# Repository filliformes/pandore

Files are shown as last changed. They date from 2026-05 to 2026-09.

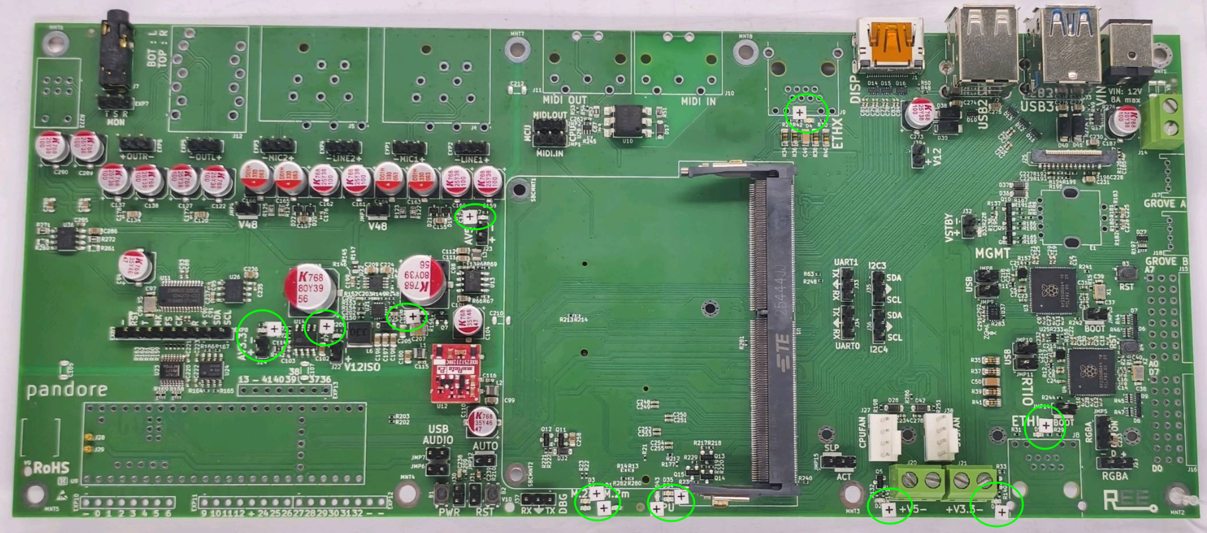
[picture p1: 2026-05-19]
doc/review/pandore-leds-review.png

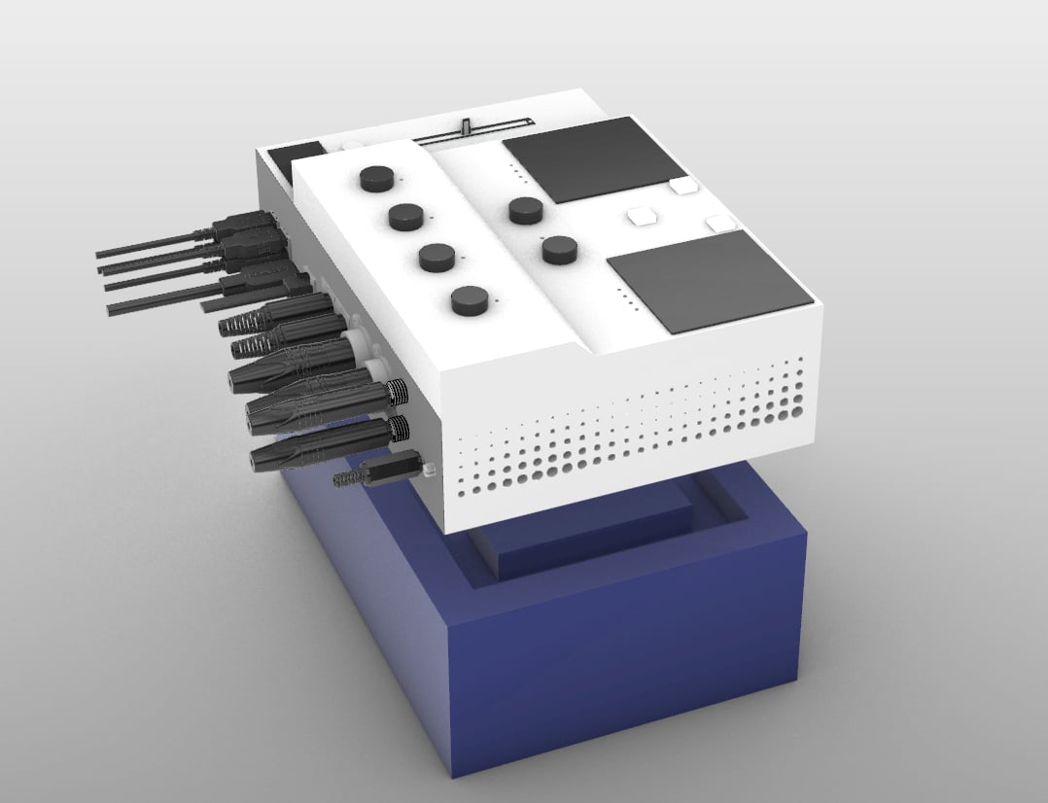
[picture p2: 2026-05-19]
doc/case+inst_v2_back.jpg

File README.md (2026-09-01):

# Pandore

Pandore A0

**Open-source digital audio instrument prototyping platform.**

Pandore is a custom-designed PCB built around the [LattePanda Mu](https://www.lattepanda.com/lattepanda-mu) compute module, a [Teensy 4.1](https://www.pjrc.com/store/teensy41.html) audio bridge, dual [RP2350](https://www.raspberrypi.com/products/rp2350/) microcontrollers, and a professional audio I/O chain. It provides a complete hardware foundation for building digital audio instruments, effects processors, and experimental sound tools.

## Status

**Revision A0** — PCBA complete at PCBWay (3 units); hand-assembly of the through-hole/DNP parts and board bring-up in progress. Manufacturing files released 2026-03-19; DRC passing. See the [interactive BOM](hw/bom/ibom.html) and the [A0 bring-up / hand-assembly guide](doc/test/bringup/pandore_a0_bringup.md).

> **PCBWay substitution:** RP2350A was unavailable at assembly time; PCBWay substituted **RP2350B (QFN-80)** for both MCU positions. RP2350A and RP2350B are binary-compatible — same cores, same peripherals, same memory map — they differ only in package size and number of exposed GPIO pins (30 vs 48). Firmware developed on RP2350A Pico boards transfers without modification.

## Board Specifications

| Parameter | Value |
|---|---|
| **Dimensions** | 260 mm x 110 mm |
| **Layers** | 4 (F.Cu / In1 / In2 / B.Cu) |
| **Components** | 804 (141 unique part numbers) |
| **Vias** | 2,217 |
| **Design tool** | KiCad 10 |

## Architecture

```
                         +-----------------+
                         |  LattePanda Mu  |
                         |  (x86-64 SBC)   |
                         +--------+--------+
                                  |
          +----------+-----------+-----------+----------+
          |          |                       |          |
 +--------+-------+  |             +---------+--------+ |
 |  RTIO MCU      |  |             |  Management MCU  | |
 |  (RP2350)      |  |             |  (RP2350)        | |
 +--------+-------+  |             +---------+--------+ |
          |          |                       |          |
 +--------+-------+  |             +---------+--------+ |
 | UART, SPI, I2C |  |             | GPIO, Power Seq, | |
 | ADC, 8x PWM    |  |             | Fan, Display     | |
 +----------------+  |             +------------------+ |
                     |                                  |
            +--------+--------+                         |
            |   Teensy 4.1    |                         |
            | (I2S-to-USB     |                         |
            |  Audio Bridge)  |                         |
            +--------+--------+                         |
                     |                                  |
            +--------+--------+               +---------+--------+
            |   CS4272 Codec  |               |   Boot, BIOS,    |
            |   (24-bit I2S)  |               |   Ethernet, M.2  |
            +-----------------+               +------------------+
```

### Compute

- **LattePanda Mu** — x86-64 SBC (Intel N100 or N305), main application processor. Recommended: DFR1147 (N100, 16 GB LPDDR5) — the N305 gives only ~13% single-core gain at ~2× cost, with no meaningful benefit for real-time audio workloads where single-thread performance dominates.
- **RTIO MCU (RP2350)** — Real-time I/O: UART, SPI, I2C, USB, ADC, 8x PWM channels
- **Management MCU (RP2350)** — System control: power sequencing, GPIO, fan, display, boot

### Audio

- **Audio/MIDI bridge:** [Teensy 4.1](https://www.pjrc.com/store/teensy41.html) — I2S-to-USB audio bridge between the CS4272 codec and the LattePanda Mu, also handles MIDI data transfer to the host computer
- **Codec:** Cirrus Logic CS4272 — stereo 24-bit ADC/DAC, I2S interface
- **Preamp:** THS4521 fully-differential amplifier + OPA1656 op-amp signal conditioning
- **Phantom power:** 48V supply via TI LM5158 flyback controller + TPS7A4001 ultra-low-noise 40V LDO post-regulation (~10 mA) for condenser microphones
- **I2S isolation:** TI ISO7762FDBQR — 6-channel digital isolator (4 forward / 2 reverse), 100 Mbps, 5000 VRMS galvanic isolation between digital and audio domains
- **I2C isolation:** TI ISO1640BDR — isolated I2C for codec control path, 2500 VRMS isolation
- **Isolated power:** Murata NXE2S1212MC-R7 — 2W isolated 12V→12V DC/DC converter (167 mA) for the isolated audio domain
- **MIDI isolation:** Isocom H11L1SMT optoisolator with Schmitt-trigger output on MIDI IN
- **Monitor output:** Dedicated headphone/speaker amplifier with hardware volume knob (Bourns PTR902-2020K-A103 — 10 kΩ audio taper, 20 mm shaft)
- **Input buffering:** Balanced input stage with line/mic switching
- **Output buffering:** Line-level outputs

### Power

| Rail | Voltage | Current | Purpose |
|---|---|---|---|
| 12V | Main input | LattePanda Mu, OLED drive |
| 5V | 2A (10W) | Digital logic, USB peripherals |
| 3.3V | 3A (10W) | MCUs, codec digital, I/O |
| 48V | 10 mA | Condenser microphone phantom power |
| AV5 / AV3P3 | — | Analog audio supply (isolated domain) |
| VSTBY | ~3.3V | Standby (CR2032 backup) |

**Power ICs:**

| Part | Role |
|---|---|
| Diodes AP63356Q (×2) | Synchronous buck converters (3.5A), main DC-DC regulation |
| STM LDL212DR (×3) | Ultra-low-dropout LDOs, local clean rails |
| ETEK ET20162 (×5) | USB VBUS current-limit load switches, 1A fixed each (U29–U32 = 4 USB-A ports, U33 = Teensy USB host) |
| TI LM5158RTER | Flyback controller for 48V phantom supply |
| TI TPS7A4001DGNR | Ultra-low-noise 40V LDO, phantom post-regulation |
| Murata NXE2S1212MC-R7 | 2W isolated 12V DC/DC (167 mA) for audio analog domain |

- Reverse-polarity, overcurrent, and overvoltage protection
- USB VBUS overcurrent handled by the ET20162 load switches (1A fixed limit each)
- PTC fuses (Bel Fuse 0ZCM0010FF2G, 0.1A) protect the **Grove ports** (J17/J18) on the standby rail
- Managed power-on sequencing via Management MCU

### Connectivity

- **Ethernet** — 2× Gigabit Ethernet via Realtek RTL8111H-CG PCIe controllers (U7, U8), 2× shielded RJ45 with isolation transformers (Würth 749020111A)
- **USB** — 4× USB-A ports (2× USB 3.0 via J3 + 2× USB 2.0 via J2) broken out from the LattePanda Mu's 8 USB lanes (remaining lanes are internal — Teensy audio bridge, AX210 WiFi/BT); plus the Teensy 4.1's own USB-C jack exposed at the back panel
- **MIDI** — 5-pin DIN IN/OUT with H11L1 optoisolation
- **Display** — 24-pin 0.5mm FPC ZIF connector (GCT FFC2A32-24-T) for OLED status display (SSD1309, 128×64 px, 1.54") — see [Components Requiring Separate Assembly](#components-requiring-separate-assembly)
- **M.2 Key-M** — PCIe x4 (NVMe SSD)
- **M.2 Key-A+E** — WiFi/Bluetooth (tested: Intel AX210 — WiFi 6E tri-band + BT 5.3) or alternate storage
- **Expansion headers** — GPIO, analog, I/O breakouts; 2× **Grove I2C connectors (3.3V, use Qwiic / STEMMA QT sensors — see below)**; I2S header; UART debug

### User Interface

- **Encoder:** Bourns PEL12T-4225T-S1024 — 24 PPR optical rotary encoder with momentary push switch and RGB LED illumination
- **Tactile switches:** 4× C&K PTS810 momentary switches (B1–B4)
- **Volume knob:** Bourns PTR902-2020K-A103 potentiometer — 10 kΩ audio taper, 20 mm shaft (monitor output level; replaces BOM part 2015K-B103, linear, 15 mm)
- **RGBA LED:** AMS-OSRAM multi-colour LEDs — blue (×3), green (×4), orange (×7), red (×1) status/indicator outputs

### Sensors

- **BMI270** — 6-axis IMU (accelerometer + gyroscope) for motion-based control

#### External sensor expansion (Grove ports)

The two Grove connectors (J17/J18) are **I2C sensor ports running at 3.3V** — each on its own management-MCU I2C bus (J17 = I2C0, J18 = I2C1), powered from the standby rail through a 0.1A PTC fuse.

Because the ports are 3.3V, use the **Qwiic / STEMMA QT** sensor ecosystem (SparkFun, Adafruit, Arduino Modulino) — it is 3.3V-native, so modules plug in safely with no level shifting. A standard **Grove-to-Qwiic adapter cable** (Adafruit #4528 or SparkFun PRT-15109) connects them. *Note: M5Stack Units are powered at 5V and are not directly compatible.*

### Flash Storage

3× Winbond W25Q128JVSIM (128 Mbit / 16 MB, QSPI):
- U2 — BIOS flash (LattePanda Mu)
- U5 — RTIO MCU flash (RP2350, U3)
- U6 — Management MCU flash (RP2350, U4)

### Thermal

- 2× 4-pin PWM fan headers (J27 CPU, J38 system), Molex KK 254 47053-1000
- **Fan header pinout: 1=GND, 2=5V, 3=Tach, 4=PWM** (fed directly from the 5V rail — note: 5V, not the 12V of a standard PC fan header)
- PWM-controlled fan driver circuit
- Three heatsink options: active cooler (DFRobot FIT0981, 5V fan), thin passive, fanless

## Audio Performance

See **[Audio Performance](AUDIO_PERFORMANCE.md)** for the full signal chain, component specs, system-level estimates, physical I/O, and performance class.

**Highlights:** 24-bit / 192 kHz, 114 dB dynamic range, -100 dB THD+N, 5000 VRMS galvanic isolation, 2× Neutrik combo XLR+TRS inputs with 48V phantom power.

## Repository Structure

```
pandore/
  hw/               Schematics (.kicad_sch) and PCB layout (.kicad_pcb)
  doc/
    arch/           Architecture diagrams (draw.io)
    img/            Board renders
    reference/      Datasheets, app notes, design guides (PDF)
  lib/              3D models (.step), KiCad symbols and footprints
  release/          Manufacturing artifacts (Gerbers, BOM, placement, 3D)
```

### Schematic Hierarchy

The top-level schematic (`pandore.kicad_sch`) references 24 sub-sheets organized by subsystem:

**Audio** — `audio`, `audio-codec`, `audio-inputs`, `audio-inbuf`, `audio-outputs`, `audio-outbuf`, `audio-isolation`, `audio-monitor`, `audio-power`

**Compute** — `computer`, `cpumod`, `mcu`, `mgmtmcu`, `rtmcu`

**Power** — `power`, `audio-power`

**Interface** — `eth`, `usbport`, `midi`, `display`, `extraport`, `mdot2`

**System** — `bootctl`, `bios`, `fan`

## Components Requiring Separate Assembly

The PCBWay PCBA order covers all SMD components. The following through-hole and DNP parts must be sourced and hand-soldered separately. BOM part numbers are listed; substitutions are noted where a different part is recommended over the original BOM.

| BOM# | Per board | Ref | Description | Part (installed) | Notes |
|---|---|-----|---|---|---|
| 40 | 1 | E1 | Encoder + RGB LED + switch | Bourns **PEL12T-4225T-S1024** | 24 PPR, push switch, RGB illuminated |
| 47 | 2 | J4, J5 | Mic/Line input combo jack | Neutrik **NCJ9FI-H-0** | XLR + 6.35mm TRS + 3-way switch |
| 50 | 2 | J8, J9 | Ethernet RJ45 | Amphenol **RJE58-188-5441** | 8P8C shielded, dual LEDs, Cat5e (replaces BOM -5411, backordered; same footprint) |
| 51 | 2 | J10, J11 | MIDI DIN | Same Sky **SDS-50J** | 5-pin DIN 180° |
| 52 | 1 | J12 | Line output TRS | Neutrik **NSJ12HF-1** | 6.35mm stacking stereo |
| 55 | 2 | J15, J16 | GPIO expansion header | Samtec **MTSW-108-22-L-T-330-RA** | 3×8 right-angle, 2.54mm pitch |
| 56 | 2 | J17, J18 | Grove connectors | TE **440055-4** | HPI 2.0mm R/A THT (replaces BOM 2041145-4, same family) |
| 105 | 1 | R273 | Headphone volume pot | Bourns **PTR902-2020K-A103** | Audio taper, 20mm shaft (replaces BOM 2015K-B103, linear, 15mm) |
| — | 1 | J25 | OLED display panel | **Microtips REX012864AYAP3N00000** (primary) or Midas MCOT128064B1V-WM (alt) | SSD1309, 128×64, 24-pin 0.5mm FPC; J25 ZIF socket is PCBWay-assembled |
| — | 1 | U9 | Audio/MIDI bridge module | **PJRC Teensy 4.1** (SparkFun DEV-20359, headerless) | Mounted on Samtec TSW headers; its own USB-C jack is exposed at the panel |
| — | 2 | J28, J29 | Teensy USB-D± pogo pins | Same Sky **CPG-23-SMT-TR** | Spring contacts tapping the Teensy's underside USB-D+/D− pads — **not** USB-C receptacles; hand-soldered |
| — | 1 | J13 | NVMe SSD | User choice | M.2 2280 Key-M, PCIe x4 |
| — | 1 | J19 | WiFi/BT module | **Intel AX210** (WiFi 6E + BT 5.3) | M.2 2230 Key-E |

---

## Manufacturing

The `release/` directory contains two packages dated 2026-03-19 (revision A0):

- **`pandore_*_A0_pcba.zip`** — PCBA package: Gerbers, drill files, BOM (.csv), pick-and-place (.pos)
- **`pandore_*_A0_release.zip`** — Full release: PCBA files + 3D assembly model (.step), assembly drawings (PDF), rendered board images, ERC/DRC reports

4-layer stackup. 2,439 drill holes. All components have manufacturer part numbers assigned.

## Reference Documentation

The `doc/reference/` directory includes datasheets and design guides used during development:

- RP2350 datasheet and hardware design guide
- LattePanda Mu evaluation kit guide and carrier board reference
- CS4272 codec (via SuperAudioBoard design guide and schematic)
- THAT1512 microphone preamp gain configuration (reference design)
- 48V phantom power supply design (TI SBOA320A + ultra-low-noise RAQ approach)
- Analog circuit design references (Analog Secrets series, AES mic preamp paper)
- THAT Corporation mic preamp reference design (git submodule)

## Requirements

- [KiCad 10](https://www.kicad.org/) to open and edit schematics and PCB layout
- [draw.io](https://app.diagrams.net/) to view architecture diagrams

## Credits

Designed by **Vincent Fillion** at [Artificiel](https://artificiel.org), with the help of **Alexandre Burton**.

Hardware engineering and KiCad source files by **Laurence Deschênes Villeneuve** ([@laurencedv](https://github.com/laurencedv)).

## License

This project is licensed under the [CERN Open Hardware Licence Version 2 — Strongly Reciprocal (CERN-OHL-S-2.0)](https://ohwr.org/cern_ohl_s_v2.txt).

You are free to use, study, modify, and distribute this design, provided that:
- You credit the original authors
- You distribute any modified versions under the same licence
- You make the source files available

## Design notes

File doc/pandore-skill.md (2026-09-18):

<!-- This document is the Pandore hardware technical reference, generated from the project's
     Claude Code skill. Personal paths, order numbers, and cost data have been removed. -->

# Pandore — Open-Source Digital Audio Instrument Prototyping Platform

Expert knowledge for developing firmware, drivers, and software for the Pandore hardware platform. Covers the complete system architecture, pin assignments, bus routing, audio signal chain, power rails, and peripheral interfaces.

**When to use:** Any work on Pandore firmware, drivers, DSP software, hardware bringup, peripheral integration, or system-level debugging.

---

## Project Location

- **Repo:** `<your local clone>/`
- **GitHub:** `filliformes/pandore`
- **Design tool:** KiCad 10
- **Status:** Revision A0 — PCBs **PCBA complete at PCBWay** (3 units), **hand-assembly + bringup in progress** (as of 2026-05-29). PCBWay received last components 2026-05-15. **iBOM and bringup doc published** by Laurence on 2026-05-19 (commit `4497a3b`): [hw/bom/ibom.html](hw/bom/ibom.html) (interactive BOM, open in browser) and [doc/test/bringup/pandore_a0_bringup.md](doc/test/bringup/pandore_a0_bringup.md) (manual-assembly checklist). Manufacturing files released 2026-03-19. The hand-assembly parts order (placed 2026-05-19) also covered the LattePanda Mu modules, Teensy boards, and active coolers, not just DNP connectors.
- **PCBWay substitution:** RP2350A unavailable; PCBWay substituted **RP2350B (QFN-80)** for both MCU positions (U3, U4). Binary-compatible — same cores, peripherals, memory map. Firmware developed on RP2350A Pico boards transfers without modification. Verify footprint accepts QFN-80 with Laurence.
- **Design by:** Vincent Fillion at [Artificiel](https://artificiel.org), with Alexandre Burton
- **Hardware engineering:** Laurence Deschênes Villeneuve ([@laurencedv](https://github.com/laurencedv))
- **Licence:** CERN-OHL-S-2.0 (strongly reciprocal — attribution + share-alike + source availability)

### Currently Available Hardware (pre-assembly dev kit)

| Item | Part | Notes |
|---|---|---|
| Host CPU | LattePanda Mu + Lite Carrier | On hand |
| Management/RTIO dev MCU | Waveshare RP2350-Plus (WAVE-29371) | 40-pin Pico 2 form factor, soldered headers, USB-C, 4MB flash |
| Networking dev | Waveshare RP2350-ETH Mini (WAVE-29266) | RP2350 + CH9121 UART-to-Ethernet chip, compact castellated form |
| OLED display | Waveshare 1.54" OLED (WAVE-25512) | SSD1309, 128×64, 7-pin SPI breakout, **onboard boost converter** |

All Management MCU firmware (display, power sequencing, IMU, fan control) is prototyped on the **RP2350-Plus** before the Pandore PCB is assembled.

> **Important difference from final board:** The Waveshare OLED module (WAVE-25512) has an **onboard boost converter** — its VCC pin accepts 3.3–5V (self-contained). The bare Midas MCOT128064B1V-WM panel on the Pandore PCB needs an **external 12V** supply on pin 23. Do not confuse the two when porting firmware.

---

## Dev Kit — Firmware Prototyping

### RP2350-Plus (WAVE-29371) — Key Facts

- **Chip:** RP2350**A** (30 GPIO) — not the RP2350B (48 GPIO) used on Pandore's RTIO MCU
- **Form factor:** 40-pin Pico 2 compatible, soldered headers
- **Flash:** 4 MB (W25Q32JV QSPI)
- **Power:** VSYS 1.8–5.5V in; 3.3V output (500 mA); USB-C
- **GPIO logic:** 3.3V only — never apply 5V to GPIO pins

**Default SPI pin assignments (Pico SDK):**

| Bus | SCK | TX (MOSI) | RX (MISO) | CSn |
|-----|-----|---|---|-----|
| SPI0 | GP18 | GP19 | GP16 | GP17 |
| SPI1 | GP10 | GP11 | GP12 | GP13 |

**Other interfaces:**

| Interface | Pins |
|---|---|
| I2C0 | GP4 (SDA), GP5 (SCL) |
| I2C1 | GP2 (SDA), GP3 (SCL) |
| UART0 | GP0 (TX), GP1 (RX) |
| UART1 | GP4 (TX), GP5 (RX) |
| ADC | GP26–GP28 (ADC0–ADC2) |

### Waveshare 1.54" OLED (WAVE-25512) — Module Pinout

7-pin header on the breakout board:

| Pin | Label | Description |
|-----|---|---|
| 1 | VCC | 3.3–5V power in (onboard boost handles OLED drive voltage) |
| 2 | GND | Ground |
| 3 | DIN | SPI MOSI (SDIN) |
| 4 | CLK | SPI SCLK |
| 5 | CS | Chip select (active low) |
| 6 | DC | Data/Command select |
| 7 | RST | Reset (active low) |

Factory default: **4-wire SPI**. I2C mode requires moving 0Ω resistors on the back of the module (not recommended — keep SPI).

### Wiring: WAVE-25512 OLED → RP2350-Plus

| OLED pin | RP2350-Plus pin | GPIO | Notes |
|---|---|---|---|
| VCC | 3V3 (pin 36) | — | Module has internal boost; 3.3V is sufficient |
| GND | GND (pin 38) | — | |
| DIN | GP19 (pin 25) | GP19 | SPI0 TX |
| CLK | GP18 (pin 24) | GP18 | SPI0 SCK |
| CS | GP17 (pin 22) | GP17 | SPI0 CSn — or manual GPIO |
| DC | GP20 (pin 26) | GP20 | Manual GPIO |
| RST | GP21 (pin 27) | GP21 | Manual GPIO |

### Software Approach for OLED

**Option A — u8g2 library (recommended for dev)**
- Constructor: `U8G2_SSD1309_128X64_NONAME0_F_4W_HW_SPI`
- Works with Pico SDK via [u8g2 Arduino port](https://github.com/olikraus/u8g2) or the [Pico-specific u8g2 port](https://github.com/Harbys/pico-ssd1306) (for SSD1306 but same pattern)
- Handles init sequence, SSD1309 command set, display buffer

**Option B — Raw Pico SDK SPI**
```c
// Init SPI0 at 10 MHz
spi_init(spi0, 10 * 1000 * 1000);
gpio_set_function(18, GPIO_FUNC_SPI); // SCK
gpio_set_function(19, GPIO_FUNC_SPI); // MOSI
gpio_init(17); gpio_set_dir(17, GPIO_OUT); // CS
gpio_init(20); gpio_set_dir(20, GPIO_OUT); // DC
gpio_init(21); gpio_set_dir(21, GPIO_OUT); // RST
```
- SSD1309 init sequence: send `0xAE` (Display Off) → config commands → clear GRAM → `0xAF` (Display On)
- Write: pull CS low, set DC high (data) or low (command), `spi_write_blocking(spi0, buf, len)`, pull CS high

**Power-up sequence (same for module and bare panel):**
1. VCC on → RST low (1 ms) → RST high → send `0xAE` → init registers → clear screen → delay 100 ms → send `0xAF`

### Build Environment (Pico SDK on Windows)

> ⚠️ **The Docker path and the official Windows installer both fail for RP2350 on this Windows dev machine** — see [Software & Firmware Development](#software--firmware-development) for the *verified working* toolchain recipe (SDK 2.1.1 cloned manually + v1.5.1 toolchain binaries + prebuilt picotool 2.1.1). What does NOT work, and why:
> - **Docker Desktop:** its WSL2 backend is disabled here (`Wsl/0x80070422`) — the daemon returns HTTP 500 on every call.
> - **`pico-setup-windows` installer:** ships **SDK 1.5.1 only**, which is RP2040-era and **cannot build RP2350** (no `rp2350-arm-s` platform). Useful only for its bundled arm-gcc / ninja / cmake binaries.

**CMakeLists.txt minimum for SPI + OLED:**
```cmake
cmake_minimum_required(VERSION 3.13)
include($ENV{PICO_SDK_PATH}/external/pico_sdk_import.cmake)
project(pandore_oled C CXX ASM)
pico_sdk_init()

add_executable(pandore_oled main.c)
target_link_libraries(pandore_oled pico_stdlib hardware_spi hardware_gpio)
pico_add_extra_outputs(pandore_oled)  # generates .uf2
```

**Flash:** hold BOOTSEL on RP2350-Plus while plugging USB → appears as mass storage → drag `.uf2` file onto it.

### RP2350-ETH Mini (WAVE-29266) — Notes

- **Ethernet chip:** CH9121 (UART-to-Ethernet bridge, not native Ethernet MAC)
- **Interface:** RP2350 talks to CH9121 over UART at configurable baud rate
- **Only 14 GPIO exposed** (castellated half-holes) — compact for integration
- CH9121 config registers set: IP, gateway, subnet, port, mode (TCP/UDP server/client) via UART commands
- Example code: `CH9120.c` / `CH9120.cpp` config files from Waveshare
- **Use case on Pandore:** prototype network-based control / OSC / remote config before Pandore PCB arrives

---

## Software & Firmware Development

How Pandore software is actually built, where it lives, and the verified toolchain — as opposed to the aspirational advice elsewhere. Written from real bring-up (2026-05).

### Host OS — Linux (CachyOS)

The LattePanda Mu host runs **Linux, specifically CachyOS** (Arch-based,
performance-tuned). Confirmed 2026-09-18. The eMMC Mu ships with Win11
preinstalled; it is wiped. This matches the production plan (one C++20 daemon,
audio via JACK/PipeWire).

**The Windows Pico-SDK toolchain saga documented below is a *dev-PC* artifact,
not the Mu target.** On Arch the RP2350 build is trivial: `arm-none-eabi-gcc` +
newlib + cmake + ninja, with `picotool` from the AUR.

Arch/CachyOS gotchas that differ from Debian/Ubuntu:

- **Serial group is `uucp`, not `dialout`** — for `/dev/ttyACM*` (RP2350 CDC and
  Teensy).
- **Python is PEP-668 externally-managed** — use `pipx`/venv or the
  `python-pyserial` pacman package for `host_bridge`; bare `pip install` fails.
- **Realtime audio:** add the user to `audio` + `realtime`, set
  `@audio - rtprio 95` and `memlock unlimited`. CachyOS's default BORE kernel is
  already low-latency.
- **udev rules** needed for flashing: `99-picotool.rules` and PJRC's
  `00-teensy.rules`.

### Firmware repo

The firmware does **not** live in this `pandore` hardware repo (that's KiCad + CERN-OHL-S). It lives in a **separate firmware repo**, MIT-licensed, laid out as:

```
<firmware-repo>/
  recherche/oled-usb-menu/        research sandbox — OLED menu prototype
    mgmtmcu_menu/                  RP2350 firmware (Pico SDK C)
      src/                         main.c, oled_ssd1309, gfx, font5x7,
                                   menu, menu_items, input, host_link, board_pins.h
      CMakeLists.txt  build.ps1  Dockerfile(dead)  README.md
    host_bridge/                   LattePanda-side Python (pyserial → Max/Pd/SC)
```

> **Status:** the menu firmware is a **throwaway prototype**. The production plan is a single C++20 daemon that owns all hardware and speaks **binary USB framing** to the two RP2350s ("Slot 0" / "Slot 1"). The prototype's text protocol is for fast iteration; it will be re-homed onto the daemon's binary framing once the concept is proven. Do not expect it to plug into `firmware/slot0` as-is.

### Verified Windows toolchain (RP2350)

The **only** combination proven to build RP2350 firmware here. Docker and the official installer both fail (see the Build Environment warning above).

| Piece | Location | How it got there |
|---|---|---|
| Pico SDK **2.1.1** | `%USERPROFILE%\pico-sdk\sdk-2.1.1` | `git clone --branch 2.1.1` + `git submodule update --init` (pulls TinyUSB etc.) |
| arm-none-eabi-gcc 10.3, cmake, ninja, python | `C:\Program Files\Raspberry Pi\Pico SDK v1.5.1\` | reused from the `pico-setup-windows` v1.5.1 install (its binaries are fine; only its SDK is too old) |
| **picotool 2.1.1** (prebuilt) | `%USERPROFILE%\pico-sdk\picotool-2.1.1\picotool` | downloaded `picotool-2.1.1-x64-win.zip` from `pico-sdk-tools` releases — the from-source build fails (no host x86 compiler) |

Key CMake settings: `PICO_BOARD=pico2`, `PICO_PLATFORM=rp2350-arm-s`. Pass `-Dpicotool_DIR=<...>\picotool` so CMake doesn't try to build picotool from source. `build.ps1` wires all of this up and takes `-Target DEVKIT|PANDORE`.

```powershell
cd <firmware-repo>\recherche\oled-usb-menu\mgmtmcu_menu
.\build.ps1                    # DEVKIT  → build-devkit\mgmtmcu_menu.uf2
.\build.ps1 -Target PANDORE    # Pandore → build-pandore\mgmtmcu_menu.uf2
```

### Dual-target pin map (`board_pins.h`)

One source tree builds for both boards via a compile-time switch (`PANDORE_TARGET` → `PANDORE_BOARD_DEVKIT` / `PANDORE_BOARD_PANDORE`). Dev-kit pins are in [Wiring: WAVE-25512 OLED → RP2350-Plus](#wiring-wave-25512-oled--rp2350-plus). The **Pandore Management MCU** map, traced from `pandore-mgmtmcu.kicad_sch` through the reusable `pandore-mcu` sub-sheet:

| Function | RP2350B GPIO | Net | Note |
|---|---|---|---|
| OLED CS | 33 | SDISP.~{SS} | SPI0 CSn |
| OLED SCK | 34 | SDISP.SCK | SPI0 SCK |
| OLED MOSI | 35 | SDISP.MOSI | SPI0 TX |
| OLED RST | 36 | SDISP.~{RST} | GPIO |
| OLED DC | 37 | SDISP.~{LATCH} | GPIO (D/C#) |
| Encoder A | 31 | ENC.A | |
| Encoder B | 30 | ENC.B | |
| Encoder BTN | 32 | ENC.BTN | |
| Enc LED R / G / B | 43 / 46 / 47 | ENC.RED/GREEN/BLUE | PWM-capable |

GPIO33/34/35 are the RP2350B's **native SPI0 alt-function pins** (datasheet Table 645), so the OLED runs on hardware SPI with no PIO. Pandore has no discrete nav buttons — the encoder owns navigation, so `BTN_PIN_*` are `-1` and `input.c` skips them.

### USB-CDC wire protocol (prototype)

Text, line-based, `\n`-terminated. Trivial to debug in a serial monitor.

```
MCU  → host:  LOAD <max|pd|sc> <path>   |  STOP  |  ENC <delta>
host → MCU:   STATUS cpu=<int> name=<text>  |  OK  |  ERR <msg>  |  INPUT <u|d|s|b>
```

`host_bridge/bridge.py` (pyserial) launches Max/Pd/SC on `LOAD`, kills on `STOP`, pushes `STATUS` ~1 Hz, and lets you drive the menu from stdin (`u/d/s/b`) when no encoder is wired. A binary **`FRAME` opcode (1024-byte 128×64 mono buffer) is reserved** for the eventual Schwung-renderer port — the day the menu is rendered host-side and pushed to a dumb display MCU.

### Expansion-header firmware map

GPIO/PWM assignments needed to write code against the expansion headers (traced from schematic — see [Expansion](#expansion) for the hardware side). **All 16 AIO/DIO signals carry a 560 Ω series resistor + TVS clamp**, so they are protected but *not* low-impedance drivers.

- **J15 AIO** (RTIO MCU): GPIO40–47 = ADC0–7, also PWM 8A–11B. Column B = VRTIO (= V3P3, unswitched, unfused). Column C = GND.
- **J16 DIO** (RTIO MCU): GPIO12,13,14,15,20,21,22,23 = PWM 6A,6B,7A,7B,2A,2B,3A,3B.
- **J17/J18 Grove** (Mgmt MCU): I2C0 = GPIO41(SCL)/40(SDA), I2C1 = GPIO39(SCL)/38(SDA). V+ is **PTC-fused** (~100 mA).
- **J33–J36** (LattePanda Mu native): UART0/1 and I2C3/4 straight off the x86 host — bypass both MCUs. GND is the centre pin (anti-reverse); no power pin.
- **J26 "RGBA"** (Mgmt MCU): dedicated **WS2812/SK6812 addressable-LED port** — GPIO on the Mgmt MCU → 74LVC1G17 buffer (5 V level shift) → data. `JMP5` selects V5 onto the port. This — not the AIO/DIO headers — is the intended way to drive an RGB LED. Direct RGB drive off AIO/DIO is starved (3.3 V through 560 Ω ≈ 2 mA red, <0.5 mA green/blue).

### Firmware targets (recap)

1. **Teensy 4.1** — Arduino/PlatformIO, Teensy Audio Library: I2S ↔ USB Audio, USB MIDI, CS4272 I²C control.
2. **RP2350B RTIO MCU** — Pico SDK: real-time I/O, ADC, 8× PWM, sensors.
3. **RP2350 Management MCU** — Pico SDK: OLED menu, encoder, RGB, power sequencing, IMU. (**Not** fans — see Thermal.) ← the `mgmtmcu_menu` prototype targets this.
4. **LattePanda Mu** — x86-64 Linux/Windows: main app host, DSP (JACK/PipeWire/ASIO), and the production daemon.

---

## System Architecture

```
                    ┌─────────────────────┐
                    │   LattePanda Mu     │
                    │   (x86-64 SBC)      │
                    │                     │
                    │  UART0-2, I2C2-5    │
                    │  8× USB (3×USB3,    │
                    │         5×USB2)     │
                    │  4× PCIe lanes      │
                    │  HDMI (DDIB)        │
                    │  BIOS (QSPI)        │
                    │  GPP_A/B/D/E/F GPIO │
                    └──┬───┬───┬───┬──┬──┘
                       │   │   │   │  │
          ┌────────────┘   │   │   │  └────────────┐
          │                │   │   │               │
    ┌─────┴──────┐   ┌────┴───┴┐  │    ┌──────────┴──────┐
    │ Teensy 4.1 │   │ RP2350B │  │    │ Management MCU  │
    │ Audio/MIDI │   │ RTIO MCU│  │    │ (RP2350)        │
    │ Bridge     │   │         │  │    │                 │
    │            │   │ 48 GPIO │  │    │ BMI270 IMU      │
    │ I2S ↔ USB  │   │ UART×2  │  │    │ (fans: see CPU) │
    │ MIDI ↔ USB │   │ SPI×2   │  │    │ Power Seq       │
    │            │   │ I2C     │  │    │ Boot/Reset      │
    │ CS4272     │   │ USB     │  │    │ Display Ctl     │
    │ codec ctl  │   │ ADC     │  │    │ RGBA LED        │
    └────────────┘   │ 8× PWM  │  │    └─────────────────┘
                     │ QSPI    │  │
                     └─────────┘  │
                                  │
                    ┌─────────────┘
                    │
            ┌───────┴───────┐
            │  Peripherals  │
            │               │
            │ Ethernet(PCIe)│
            │ M.2 Key-M     │
            │ M.2 Key-A+E   │
            │ HDMI display  │
            │ Expansion hdr │
            └───────────────┘
```

---

## Audio Subsystem

### Signal Chain

```
Mic/Line Input → THS4521 Diff Amp + OPA1656 → Input Buffer → CS4272 ADC
                                                       │
                                                   I2S bus
                                                       │
                                              ┌────────┴────────┐
                                              │   Teensy 4.1    │
                                              │  (I2S ↔ USB     │
                                              │   Audio Bridge) │
                                              └────────┬────────┘
                                                       │
                                                  USB Audio
                                                       │
                                                LattePanda Mu
                                                       │
                                                  USB Audio
                                                       │
                                              ┌────────┴────────┐
                                              │   Teensy 4.1    │
                                              └────────┬────────┘
                                                       │
                                                   I2S bus
                                                       │
                                              CS4272 DAC → Output Buffer → Line Out
                                                                        → Monitor Amp (volume knob) → Headphones
```

### CS4272 Codec (U11)

- **Part:** CS4272K-CZZR (Cirrus Logic)
- **Format:** I2S, 24-bit, up to 192 kHz
- **Datasheet:** https://statics.cirrus.com/pubs/proDatasheet/CS4272_F2.pdf

**I2S Signals:**
| Signal | Description |
|---|---|
| `DATA.TXD0` | I2S transmit data (ADC → MCU) |
| `DATA.RXD0` | I2S receive data (MCU → DAC) |
| `DATA.TXFS` | I2S frame sync (LRCLK) |
| `DATA.TXCLK` | I2S bit clock (BCLK) |
| `DATA.MCLK` | Master clock |

**Control (I2C):**
| Signal | Description |
|---|---|
| `CTL.SDA` | I2C data |
| `CTL.SCL` | I2C clock |

**Audio Signals:**
| Signal | Description |
|---|---|
| `LEFT.SIG+`, `LEFT.SIG-` | Balanced line output L |
| `RIGHT.SIG+`, `RIGHT.SIG-` | Balanced line output R |
| `MICLINE1.SIG+`, `MICLINE1.SIG-` | Mic/line input 1 |
| `MICLINE2.SIG+`, `MICLINE2.SIG-` | Mic/line input 2 |
| `~{MUTE}.L`, `~{MUTE}.R` | Mute control (active low) |
| `VCM0`, `VCM1`, `VCM2` | Virtual ground references |

**Hierarchical I2S Bus Labels (inter-sheet routing):**
| Label | Description |
|---|---|
| `CODEC{I2S1DPX}` | Codec-side I2S bus |
| `CPU{I2S1DPX ~{RST}}` | LattePanda Mu I2S bus |
| `MCU{I2S1DPX ~{RST}}` | RP2350 MCU I2S bus |
| `DATA{I2S1DPX}` | Data-side I2S bus |
| `AUDMST{I2C}` | Audio master I2C bus |
| `CODEC{I2C}` | Codec I2C bus |

**Audio Domain Isolation:**

| Part | Designator | Type | Role |
|---|---|---|---|
| TI ISO7762FDBQR | U23 | 6-ch digital isolator, 100 Mbps, 5000 VRMS | I2S bus isolation (4 fwd / 2 rev) |
| TI ISO1640BDR | U24 | Isolated I2C, 1 Mbps, 2500 VRMS | Codec I2C control isolation |
| Murata NXE2S1212MC-R7 | U12 | **2W** isolated DC/DC, 12V→12V (167 mA, ±1500 VDC isolation) | Isolated power for VSSISO domain — **PCBWay-assembled**, see schematic `pandore-audio-power` |
| Isocom H11L1SMT | U10 | Optoisolator with Schmitt trigger | MIDI IN isolation |

- Separate analog ground (AVSS, VSSISO) from digital ground (VSS)
- ±8 kV IEC 61000-4-2 contact discharge ESD protection on ISO7762

### Microphone Preamp

- **Differential amplifier:** TI THS4521IDGKR (U15, U16, U17, U18) — fully-differential, low-noise, wideband
- **Signal conditioning:** TI OPA1656IDR (U26, U34, U35, U36) — dual low-noise op-amp (SOIC8)
- **Reference docs:** THAT1512 DN138 and thatmicpre submodule (reference designs, not used in final BOM)

### 48V Phantom Power

- Ultra-low-noise step-up converter
- ~10 mA output (sufficient for condenser microphones)
- Passive output filtering
- Design references: TI SBOA320A, RAQ ultra-low-noise approach

### Monitor Output

- Dedicated headphone/speaker amplifier
- **Volume knob:** Bourns PTR902 dual-gang potentiometer with rotary switch (R273, DNP)
  - **BOM part:** PTR902-2015K-B103 (10 kΩ, linear taper, 15 mm shaft)
  - **Installed part:** PTR902-2020K-A103 (10 kΩ, **audio taper**, **20 mm shaft**) — longer shaft for panel clearance; audio taper gives more natural volume feel (Mouser: 652-PTR902-2020KA103)
  - Footprint: `reekilib_pot:bourns_PTR902` (same for both shaft lengths)
- Independent from line outputs

#### Verified from Rev A0 netlist — R273 wiring, isolation, and the rotary switch

R273 is an 8-pad part: two audio gangs plus a rotary switch. Pad → net, from
`pandore.kicad_pcb`:

| Pad | Net | Function |
|---|---|---|
| 1 | `Net-(U34A-OUT)` | L signal in, from OPA1656 `U34A` |
| 2 | `Net-(R264-Pad1)` | **L wiper** → `R264` (5.1 kΩ) |
| 3 | `Net-(U36A-IN-)` | `U36A` inverting input |
| 4 | `Net-(U35A-OUT)` | R signal in, from `U35A` |
| 5 | `Net-(R269-Pad1)` | **R wiper** → `R269` (5.1 kΩ) |
| 6 | `Net-(U36B-IN-)` | `U36B` inverting input |
| 7 | `AV5` | rotary switch pole |
| 8 | `Net-(U34A-V+)` | rotary switch pole → monitor op-amp V+ rail |

Both wipers feed 5.1 kΩ resistors into an OPA1656 summing junction — a
Baxandall-style **active** volume control, not a plain divider to ground.
This is why the monitor path keeps its noise performance at low settings.

**The pot cannot be read by any processor, and must not be wired to one.**
Neither wiper reaches an ADC anywhere on the board. The whole monitor chain
(`U34`/`U35`/`U36`, the pot) runs on `AV5` referenced to **`AVSS`** — the
isolated analog domain. Exactly 12 components bridge `VSS` (digital) and
`AVSS`, and every one is either an isolator or a barrier capacitor:

- `U23` ISO7762 (I²S), `U24` ISO1640 (I²C), `U12` NXE2S1212 (isolated DC/DC)
- `C105`–`C109`, `C210`–`C213` — AC coupling across the barrier

There is **no 0 Ω link, ferrite, or star point** joining the two grounds; they
are separate at DC. Running a wire from a wiper to a Teensy or MCU ADC would
short the barrier, destroying the 5000 V<sub>RMS</sub> isolation and injecting
digital ground noise into the analog ground — which is precisely what the
isolation exists to prevent, and what the 114 dB dynamic-range figure depends
on.

**If you want software-readable volume, use one of these instead:**

1. **Encoder + codec digital volume (recommended).** The Mgmt MCU already owns
   the encoder and can write the CS4272 DAC volume registers (`0x04`/`0x05`)
   over the existing isolated I²C. Affects both outputs, no new hardware, no
   isolation compromise. The analog pot stays as the final headphone trim
   after the DAC, which is the correct place for it.
2. **I²C ADC on the isolated side.** `EXP8` is a populated 2-pin header on
   `CTL.SDA`/`CTL.SCL` — the codec side of `U24`, already in the AVSS domain.
   An ADS1115 there (powered from `AV3P3`/`AV5`, buffered off the wiper) is
   readable through the isolator that is already in place. Note that bus
   carries **ERR-001**, so any add-on must follow the same swapped convention
   as the codec (its SCL to `EXP8.2`, its SDA to `EXP8.1`).
3. **Digital pot or VCA** in the signal path, commanded over the isolated I²C.
   Rev B territory.

**Rotary switch — live, and a bring-up gotcha.** Pads 7/8 sit in parallel with
`R275`, which links `AV5` to the monitor op-amps' V+ rail. `R275` is **0 Ω and
marked DNP**, so on Rev A0 boards the switch is *not* bypassed: the monitor
op-amps are powered only when the switch is closed. **If the headphone output
is dead, check the knob is not at the off detent before suspecting the
amplifier.** Fitting a 0 Ω at `R275` defeats the switch and makes the monitor
stage always-on. The switch is not connected to any MCU either, so it cannot
be read in software.

### Audio Power Rails

| Rail | Description |
|---|---|
| `AV3P3` | 3.3V analog supply |
| `AV5` | 5V analog supply |
| `AVSS` | Analog ground |
| `VSSISO` | Isolated analog ground |

### Physical Audio I/O

| Connector | Part | Type |
|---|---|---|
| Mic/Line In (×2) | Neutrik NCJ9FI-H-0 | Combo XLR + 6.35mm TRS + 3-way switch |
| Line Out (×1) | Neutrik NSJ12HF-1 | 6.35mm TRS |
| Monitor | Same Sky SJ3-35083B-TR | 3.5mm TRS |
| MIDI In/Out | Same Sky SDS-50J (×2) | 5-pin DIN |
| Teensy USB-D± tap (J28, J29) | Same Sky CPG-23-SMT-TR (×2) | **Pogo pin** (spring contact, NOT USB-C). Contacts Teensy's bottom-side USB-D+/D- pads. Teensy's own USB-C jack is what's exposed at Pandore's panel. |

### Audio Performance

**Component-level specs:**

| Component | Role | Key Specs |
|---|---|---|
| CS4272 (Cirrus Logic) | Stereo codec | 24-bit, 4–192 kHz, 114 dB DR (A-wtd), -100 dB THD+N |
| THS4521 (TI, ×4) | Fully-diff amp | 4.6 nV/√Hz, -112 dB THD+N @ 1 kHz, 145 MHz BW, 490 V/µs, 102 dB CMRR |
| OPA1656 (TI, ×4) | Dual op-amp | 2.9 nV/√Hz, -131 dB THD @ 1 kHz, 53 MHz GBW, 24 V/µs |
| ISO7762 (TI) | I2S isolator | 6-ch, 100 Mbps, 11 ns delay, 5000 VRMS |

**System-level estimates** (CS4272 codec is the limiting factor, not the analog front-end):

| Parameter | Expected Value |
|---|---|
| Dynamic range | 112–114 dB (A-weighted) |
| THD+N (system) | -98 to -100 dB (codec-limited) |
| Noise floor | ~-114 dBFS (A-weighted) |
| Max sample rate | 192 kHz / 24-bit |
| USB audio latency | ~5–10 ms round-trip (buffer-dependent) |
| Frequency response | 20 Hz – 90 kHz (at 192 kHz) |
| Phantom power | 48V / 10 mA |
| Channel separation | >100 dB |
| Galvanic isolation | 5000 VRMS (digital ↔ audio domain) |

**Performance class:** Comparable to prosumer interfaces (Focusrite Scarlett, MOTU M4). The analog front-end is essentially transparent — the OPA1656's -131 dB THD provides substantial headroom over the codec. The 114 dB dynamic range is well above the noise floor of any instrument prototyping scenario.

---

## Teensy 4.1 — Audio/MIDI Bridge

- **Part:** PJRC Teensy 4.1 (NXP i.MX RT1062, ARM Cortex-M7 @ 600 MHz)
- **Sourcing:** SparkFun **DEV-20359** (headerless Teensy 4.1) at Mouser is the version Vincent used
- **Footprint:** `reekilib_som:teensy_4.1` — 2.54 mm pitch THT, 24+24 long-row pins + 5-pin USB host row
- **Datasheet:** https://www.pjrc.com/store/teensy41.html
- **Role:** Bridges I2S audio and MIDI data between the CS4272 codec and the LattePanda Mu over USB

### Mounting — direct-solder header stack

The Teensy is held entirely by **soldered pin headers** (no separate mechanical screws). Both boards share a single set of male pin headers; the plastic insulator acts as a fixed mechanical spacer between the two PCBs.

```
       ┌─────────────────────┐  ← Teensy 4.1 PCB top  (solder pins here)
       │ Teensy 4.1 (1.6 mm) │
       ├─────────────────────┤  ← Teensy bottom (rests on plastic)
       │   plastic 2.54 mm   │  ← INSULATOR = board-to-board gap
       ├─────────────────────┤  ← Pandore PCB top (rests on plastic)
       │ Pandore PCB (1.6 mm)│
       └─────────────────────┘  ← Pandore PCB bottom (solder pins here)
```

| Qty per board | Part | Mouser # | Notes |
|---|---|---|---|
| 2 | Samtec **TSW-124-07-T-S** | 200-TSW12407TS | 24-pin male, 2.54 mm pitch, **2.54 mm plastic** (sets the gap), mating post 5.84 mm / termination post 2.54 mm, tin |
| 1 | Samtec **TSW-105-07-T-S** | 200-TSW10507TS | 5-pin male, same family, for USB host row |

> ⚠️ **The 2.54 mm gap puts the CPG-23 pogo pins (J28/J29) at near-maximum compression.** CPG-23 working height is 2.50–2.90 mm (normal 2.70). 2.54 mm is within spec but only 0.04 mm above the max-compression limit. Reliable for static mount but tight — if a future revision adjusts the gap target, switching to a header with a 2.70 mm insulator would be ideal.

### USB-D± routing (J28, J29 pogo pins)

Pandore taps the Teensy's bottom-side USB-D+/D- exposed pads via **2× spring-loaded pogo pins** at positions J28 and J29:

| Position | Signal | Part |
|---|---|---|
| J28 | `AUDIO.D-` | Same Sky CPG-23-SMT-TR (Ø1.80 mm pad / Ø1.35 mm hole) |
| J29 | `AUDIO.D+` | Same Sky CPG-23-SMT-TR (Ø1.80 mm pad / Ø1.35 mm hole) |

When the Teensy is socketed onto its TSW header stack, the pogo pins make spring contact with the Teensy's underside pads — wiring USB-D± from the Teensy into Pandore's audio USB lane (`AUDIO.USB{USB2}` → LattePanda Mu) without any wires. The Teensy's own USB-C jack remains accessible at Pandore's back panel for direct user connection.

**Soldering order matters when stacking:**
1. Hand-solder the **CPG-23 pogo pins** to J28, J29 first (Pandore PCB, fine SMT work)
2. Insert TSW pin headers into Pandore PCB through-holes, plastic insulators flush on top
3. Set the Teensy on top, pins through its through-holes
4. Solder the **Teensy side first** (top pins) — locks the geometry
5. Flip and solder the Pandore PCB side

**Teensy Connections:**

| Teensy Pin/Bus | Connected To | Description |
|---|---|---|
| `CODEC{I2S1DPX}` | CS4272 I2S bus | I2S audio data to/from codec |
| `CPU{I2S1DPX ~{RST}}` | LattePanda Mu | I2S passthrough / USB audio |
| `MCU{I2S1DPX ~{RST}}` | RP2350 MCU | I2S interface to RTIO MCU |
| `USBH.VUSB` | USB host power | USB host bus voltage |
| `USBH.D-`, `USBH.D+` | USB host data | USB host data lines |
| `USBD.VUSB` | USB device power | USB device bus voltage |
| `USB{USB2}` | LattePanda Mu | USB 2.0 connection to host CPU |

#### USB path to the host — and the power gate that bites

The Teensy reaches the Mu on **`USB2_P6` (edge pins 112/114)** via the `J28`/`J29`
pogo pins and series jumpers **`JMP6`/`JMP7`**.

> **The confound that makes a pogo-path test meaningless if skipped.** The
> Teensy's `VIN` is **unconnected**. On the pogo path its *only* supply is
> `USBD.VUSB` (pad 59) ← **`U33`** (ET20162 load switch) ← `V5`, whose **enable is
> `AUDIO.EN` = Mu `GPP_F12`**. If the host never drives `GPP_F12` high, `U33`
> stays off, the Teensy is unpowered, and it will not enumerate **on any BIOS**.
> With a USB-C cable it is powered by that port's VBUS instead — which is why
> cabling "works" and the pogo path appears dead.
>
> Any pogo-path test must: (1) fit `JMP6`/`JMP7`, (2) drive `GPP_F12` high,
> (3) measure 5 V on Teensy pad 59. Only then does a negative result implicate
> the BIOS. **The pin-13 LED is not a power indicator.**
>
> **The production daemon must assert `GPP_F12` as part of power sequencing, or
> there is no audio interface at all.**

Also: stock Mu BIOS declares `USB2_P6` "dedicated for USB Type-C ... cannot be
used as a standard USB port". LattePanda's own design guide confirms this is
**firmware policy, not silicon**. Bench-confirmed 2026-09-13: with `JMP6`/`JMP7`
fitted and 5 V present, the Teensy does **not** enumerate over the pogo path on
stock BIOS, but **does** when cabled from its own USB-C to a Pandore USB-A port.
Device and firmware are fine; the port is the difference.

Leave the Teensy's underside `VUSB`↔`VIN` pads **intact** — the common "cut for
external power" mod kills the pogo path. No spare USB2 lane exists as a
fallback; all 8 are allocated.

**Firmware responsibilities:**
1. Class-compliant USB Audio device (I2S ↔ USB bridge)
2. MIDI data transfer (DIN → USB MIDI → LattePanda Mu) — **only when
   `JMP1`/`JMP2` are set to the Teensy (1–2)**; the DIN ports are
   jumper-shared with the Mu's UART2. Teensy side is `Serial8`
   (IO34 RX / IO35 TX). See [MIDI Interface](#midi-interface).
3. Codec I2C control (configuration, sample rate, gain)

---

## RP2350B — RTIO MCU (U3)

- **Part:** RP2350B-TR13 / RP2350B-TR7 (Raspberry Pi)
- **Core:** Dual ARM Cortex-M33 or dual RISC-V Hazard3 @ 150 MHz
- **Package:** QFN-80 (48 GPIO) — PCBWay substituted RP2350B for RP2350A; same binary interface, only differs in package footprint
- **Flash:** W25Q128JVSIM (128 Mbit = 16 MB, QSPI) — same part used for all 3 processors (U2/U5/U6)

### GPIO Map (48 lines: GPIO0–GPIO47)

All 48 GPIOs are exposed via hierarchical labels. Key alternate functions:

| Function | Pins |
|---|---|
| UART0 TX/RX | Configurable (any GPIO via PIO) |
| UART1 TX/RX | Configurable (any GPIO via PIO) |
| SPI0 (MOSI/MISO/SCK/CS) | Configurable |
| SPI1 (MOSI/MISO/SCK/CS) | Configurable |
| I2C | Configurable |
| USB D+/D- | GPIO7 / GPIO6 |
| ADC | GPIO26-GPIO29 (ADC0-ADC3) |
| PWM | 8 channels on configurable pins |

**USB Signals:**
| Signal | GPIO | Description |
|---|---|---|
| `_USB.D+` / `USB.D+` | GPIO7 | USB data positive |
| `_USB.D-` / `USB.D-` | GPIO6 | USB data negative |

**QSPI Flash Bus:**
| Signal | Description |
|---|---|
| `QSPI.SCK` | SPI clock |
| `QSPI.D0`–`QSPI.D3` | Quad SPI data |
| `QSPI.~{CS}` | Chip select (active low) |

---

## Management MCU (RP2350)

Connected to the LattePanda Mu for system-level control.

### Responsibilities

- Power-on sequencing
- Boot/reset control
- Display management
- RGBA LED output
- BMI270 IMU reading

### BMI270 IMU

- **Type:** 6-axis (accelerometer + gyroscope)
- **Interface:** I2C or SPI (connected to management MCU)
- **Use case:** Motion-based instrument control (tilt, shake, orientation)

### Fan Control — *not* owned by this MCU

> **Correction (verified 2026-09 from the netlist).** The fans are driven by the
> **LattePanda Mu**, not the Management MCU. `FANCPU{TAC PWM}` and
> `SYSCPU{TAC PWM}` terminate in `pandore-cpumod.kicad_sch` on the Mu's native
> `FAN_CTL`/`FAN_TAC` edge pins. The strings `FANCPU`/`SYSCPU` appear **zero**
> times in `pandore-mgmtmcu.kicad_sch`. Confirmed independently by Laurence.
>
> Consequence: fan speed is handled by the Mu's BIOS/OS thermal management
> (ACPI / `hwmon` on Linux). **No MCU firmware is needed, or able, to control
> them.** See [Thermal](#thermal).

### OLED Status Display

#### Selected Part

- **Part:** Midas Displays MCOT128064B1V-WM
- **Source:** DigiKey.ca (PN: MCOT128064B1V-WM, DigiKey #21322651)
- **Datasheet:** https://www.farnell.com/datasheets/2830019.pdf
- **Alternate sources:** Farnell (PN 2817922), RS Components (PN 249-2717)

#### Display Specifications

| Parameter | Value |
|---|---|
| Type | Graphic OLED, passive matrix, COG (chip-on-glass) |
| Resolution | 128 × 64 pixels |
| Diagonal | 1.54" |
| Driver IC | SSD1309ZC |
| Appearance | White on black |
| Module size | 42.04 × 27.22 × 1.45 mm |
| Active area | 35.05 × 17.51 mm |
| Pixel pitch | 0.274 × 0.274 mm |
| Contrast ratio | 2000:1 |
| Brightness | 100–120 cd/m² (50% checkerboard) |
| Viewing angle | 160° (H/V) |
| Operating temp | -40°C to +80°C |
| OLED lifetime | 20,000 hours (25°C, 50% checkerboard) |

#### Electrical Characteristics

| Parameter | Symbol | Min | Typ | Max | Unit |
|---|---|-----|-----|-----|---|
| Logic supply | VDD | 2.80 | 3.00 | 3.30 | V |
| Display supply | VCC | 12.00 | 12.50 | 13.00 | V |
| Operating current (50% checker) | IDD | — | 16 | 45 | mA |

#### FPC Connector

- **FPC:** 24-pin, 0.5 mm pitch, top contact
- **Mating connector:** GCT FFC2A32-24-T (ZIF, slide lock, SMT)
- **FPC contact width:** P0.5 × 23 = 11.5 mm

#### Pinout (24-pin FPC)

| Pin | Symbol | Function | Pandore Connection (SPI mode) |
|-----|---|---|---|
| 1 | NC (GND) | No connection | GND |
| 2 | VLSS | Analog ground | VSS |
| 3 | VSS | Ground | VSS |
| 4 | NC | No connection | — |
| 5 | VDD | Logic supply (2.8–3.3V) | **VSTBY** rail (≈3.3V standby, LDO U27) — verified from Rev A0 netlist |
| 6 | BS1 | Interface select | VSS (= 0 for SPI) |
| 7 | BS2 | Interface select | VSS (= 0 for SPI) |
| 8 | CS# | Chip select (active low) | Management MCU GPIO |
| 9 | RES# | Reset (active low) | Management MCU GPIO |
| 10 | D/C# | Data/Command select | Management MCU GPIO |
| 11 | R/W# | Read/Write (SPI: tie low) | VSS |
| 12 | E/RD# | Enable/Read (SPI: tie low) | VSS |
| 13 | D0 | SPI: SCLK | Management MCU SPI CLK |
| 14 | D1 | SPI: MOSI (SDIN) | Management MCU SPI TX |
| 15 | D2 | SPI: NC | — |
| 16–20 | D3–D7 | Unused in SPI (tie low) | VSS |
| 21 | IREF | Segment current ref | Resistor to VSS (set 10 µA) |
| 22 | VCOMH | COM deselected voltage | **10 µF** cap to VSS (C230) — verified from Rev A0 netlist |
| 23 | VCC | Display drive (12–13V) | `V12` rail + **10 µF (C231) ‖ 100 nF (C228)** — verified from Rev A0 netlist |
| 24 | NC (GND) | No connection | GND |

#### Power Integration with Pandore

- **VDD (logic):** Connect directly to Pandore `VSTBY` rail (≈3.3V always-on standby, from LDO U27 LDL212DR) — **not** `V3P3`; verified from the Rev A0 netlist (J25 pad 5 → VSTBY)
- **VCC (OLED drive):** Connect directly to Pandore `V12` rail (12V) — within the 12.0–13.0V spec range, no boost converter needed
- **Ground:** Connect to `VSS` (digital ground domain, not AVSS)
- **IREF resistor:** R = (VCC − 3.5V) / 10 µA. For VCC = 12V: R ≈ 850 kΩ (nearest standard: 820 kΩ or 910 kΩ). Fine-tune for desired brightness.

#### Software

- **u8g2 constructor:** `U8G2_SSD1309_128X64_NONAME0_F_4W_HW_SPI`
- **Pico SDK SPI:** Standard `spi_write_blocking()` with manual CS/DC GPIO control
- **Interface:** 4-wire SPI (fastest option, recommended over I2C)
- **Power-up sequence:** VDD first → send Display Off → init → clear screen → VCC on → delay 100 ms → Display On
- **Power-down sequence:** Display Off → VCC off → delay 100 ms → VDD off

#### IREF and VCOMH

- **IREF (pin 21):** R = (VCC − 3.5V) / 10 µA. For VCC = 12.5V (typ): R ≈ 900 kΩ → use **910 kΩ** (R196 in BOM, confirmed). For 12.0V: ~850 kΩ. Fine-tune for desired brightness.
- **VCOMH (pin 22):** Bypass cap to VSS — **10 µF** (C230), verified from the Rev A0 netlist (earlier docs said 2.2 µF / 4.7 µF — both wrong)

#### Verified from Rev A0 netlist (J25 pad → net, from `pandore.kicad_pcb`)

Ground truth for the OLED socket, pulled from the PCB's per-pad net assignments (not inferred from the schematic). This settles a recurring misdiagnosis that the SSD1309 VCC is stuck at 3.3 V:

- **Pin 23 (VCC, OLED drive) → `V12`.** The panel drive voltage is the board's 12 V input rail. There is **no boost converter, and none is needed** — Pandore is fed 12 V from the barrel jack (J6, PJ-063BH), and V12 is the *highest* rail; the AP63356 bucks (U19/U20) step it *down* to 5 V/3.3 V. (The only boost on the board is the 48 V phantom supply, LM5158 in `pandore-audio-power` — unrelated.) So "no boost anywhere" is true but irrelevant: a 12 V-fed board already has 12 V.
- **Pin 5 (VDD, logic) → `VSTBY`** (≈3.3 V standby), a *different* net from VCC. VCC and VDD are not the same rail.
- **VCC decoupling:** `C231` = **10 µF** / 25 V X5R (0805) ‖ `C228` = **100 nF** / 25 V X7R (0402), both V12→VSS, placed ~6 mm from J25. J25 is the **only** V12 consumer on the Mgmt MCU sheet, so these are unambiguously the panel's decoupling. Note `C230` (VCOMH) and `C231` (VCC bulk) are the *same* part number, GRM21BR61E106KA73K — easy to confuse when hand-populating.
- **BS1/BS2 (pins 6/7):** strap-select. R194/R195 (0 Ω → VSS) **populated**; R192/R193 (10 kΩ → VSTBY) **DNP** → BS1 = BS2 = 0 → **4-wire SPI**.
- **Signals:** CS# (8) → `SDISP.~{SS}`, RES# (9) → `SDISP.~{RST}`, **D/C# (10) → `SDISP.~{LATCH}`** (repurposed net name — the pin most likely to bite firmware if CS/DC are swapped), SCLK (13) → `SDISP.SCK`, SDIN (14) → `SDISP.MOSI`. R/W#, E/RD#, D3–D7 → VSS. IREF (21) → R196 = 910 kΩ → VSS. VCOMH (22) → C230 = 10 µF → VSS.

**Blank-but-powered bring-up checklist** (12 V confirmed at pin 23, panel dark):
1. **FFC seating** — top-contact 24-pin flex, latch fully closed, contacts facing the right way. By far the most common cause.
2. **Firmware pin mapping** — scope CS/DC/SCK/MOSI *at the connector*; confirm D/C# (`SDISP.~{LATCH}`) and CS# (`SDISP.~{SS}`) aren't swapped in firmware.
3. **12 V holds under load** (16–45 mA) and VCC local decoupling present.
4. **Contrast (0x81) not left at 0**; VDD-before-VCC power-up order.
5. **Continuity sanity:** BS1→VSS and BS2→VSS ≈ 0 Ω (confirms R194/R195, not R192/R193); IREF→VSS ≈ 910 kΩ.

#### Sourcing Options

| Manufacturer | Part Number | Notes | Source |
|---|---|---|---|
| Microtips/Raystar | **REX012864AYAP3N00000** | SSD1309, 128×64, yellow emitting, same 24-pin FPC — **primary choice** | Mouser 668-REX012864AYAP3N |
| Midas Displays | MCOT128064B1V-WM | SSD1309, 128×64, white emitting — **alternate** | DigiKey.ca #21322651 |
| Generic (Amazon) | JESSINIE 1.54" SSD1309 24-pin | Bare COG panels, verify 24-pin before ordering | Amazon.ca |

#### Dev Prototyping Setup

For firmware development before Pandore PCB arrives:

- **Display module:** Waveshare WAVE-25512 (1.54" OLED, SSD1309, 7-pin SPI header breakout — same panel on a PCB)
- **MCU board:** Waveshare RP2350-Plus (WAVE-29371) — full 40-pin Pico 2 pinout, best for display driver dev
- **Ethernet board:** Waveshare RP2350-ETH (WAVE-29266) — for networking experiments
- **Source:** ABRA Electronics, Montreal (local pickup)

---

## LattePanda Mu — Host CPU (U1)

- **Architecture:** x86-64, Intel Processor N100 (4 cores, up to 3.4 GHz) or N305 (8 cores, up to 3.8 GHz)
- **Recommended variant:** DFR1146 (N100, 8 GB LPDDR5) or **DFR1147 (N100, 16 GB LPDDR5, preferred)** for Max/MSP and heavy DSP workloads
- **Board configuration (3 boards):** 1× **DFR1147** (N100, 16 GB — Mouser, the preferred heavy-DSP unit) + 1× **DFR1146** (N100, 8 GB — Mouser) + 1× **LattePanda Mu 8 GB Evaluation Kit** (Amazon, Jan 2026, ASIN B0D4VC43HC = Mu + Lite Carrier, the firmware dev unit). Net fleet: **two 8 GB + one 16 GB**. Only **2× FIT0981 active coolers** were bought for the 3 boards — the third has no active cooler yet.
- **N100 vs N305:** N305 gives only ~13% single-core gain (GB6: 1217→1376) at ~2× price — not worth it for real-time audio where single-thread performance dominates. The 16 GB RAM is more valuable than the extra cores.
- **Geekbench 6:** N100 = 1217 single / 3115 multi; N305 = 1376 single / 5249 multi
- **TDP:** Configurable 6W–35W (6W passive, 35W active cooling)
- **Power rails:** V3P3 (3.3V), V12 (12V)

### Exposed Interfaces

**UART:**
| Bus | Description |
|-----|---|
| `UART0{UART}` | General purpose |
| `UART1{UART}` | General purpose |
| `UART2{UART}` | General purpose |
| `AUDIO.MIDI{UART}` | MIDI data (via Teensy USB) |

**I2C:**
| Bus | Description |
|-----|---|
| `I2C2{I2C}` | Peripheral bus |
| `I2C3{I2C}` | Peripheral bus |
| `I2C4{I2C}` | Peripheral bus |
| `I2C5{I2C}` | Peripheral bus |

**USB (8 lanes from LattePanda Mu — NOT 8 user-facing ports):**

> **Important distinction.** The LattePanda Mu exposes **8 USB lanes** (logical) to the carrier. Pandore breaks them out into **only 4 user-facing USB-A receptacles**: J2 (USB2-A_2stacked, Same Sky 61400826021) = 2× USB 2.0 ports stacked, and J3 (USB3-A_2stacked, Amphenol 1003-004-01010) = 2× USB 3.0 ports stacked. The remaining lanes are routed internally (Teensy audio bridge, Intel AX210 WiFi/BT M.2 module, etc.). The only panel USB-C is the **Teensy 4.1's own onboard USB-C jack**, exposed at the back panel; J28/J29 are **not** USB-C receptacles — they are CPG-23 pogo pins that tap the Teensy's underside USB-D± pads (see Physical Audio I/O). **When writing for non-technical audiences (sub, paper, presentation): say "4 USB-A ports + 1 USB-C (Teensy)", not "8 USB".**

| Lane | Type | Description |
|---|---|---|
| `USBP1{USB3}` | USB 3.0 | → J3 (front USB-A) |
| `USBP2{USB3}` | USB 3.0 | → J3 (front USB-A) |
| `USBP3{USB2}` | USB 2.0 | → J2 (front USB-A) |
| `USBP4{USB2}` | USB 2.0 | → J2 (front USB-A) |
| `USBP5{USB2}` | USB 2.0 | Internal (M.2 / WiFi+BT) |
| `USBP6{USB2}` | USB 2.0 | Internal |
| `USBP7{USB2}` | USB 2.0 | Internal |
| `USBP8{USB2}` | USB 2.0 | Internal |
| `AUDIO.USB{USB2}` | USB 2.0 | Teensy audio bridge — **routed via 2× pogo pins (J28/J29 = Same Sky CPG-23-SMT-TR) that contact the Teensy's bottom-side USB-D+/D- pads**. The Teensy's own front-edge USB-C jack is what's exposed at Pandore's back panel. |

**PCIe:**
| Lane | Type | Description |
|---|---|---|
| `PCIEP0{PCIE1X}` | PCIe x1 | Ethernet / peripheral |
| `PCIEP1{PCIE1X}` | PCIe x1 | Peripheral |
| `PCIEP2{PCIE1X}` | PCIe x1 | Peripheral |
| `PCIEP3{PCIE4X}` | PCIe x4 | NVMe M.2 / high-bandwidth |

**Display:**
| Signal | Description |
|---|---|
| `DISP{HDMI}` | HDMI output (DDIB bus) |

**GPIO (directly exposed):**
| Pin | Description |
|-----|---|
| `GPP_A12` | General purpose |
| `GPP_B11`, `GPP_B14` | General purpose |
| `GPP_D0`, `GPP_D2`, `GPP_D3` | General purpose |
| `GPP_E0` | General purpose |
| `GPP_F12`–`GPP_F16` | General purpose (5 pins) |

**System Control:**
| Signal | Description |
|---|---|
| `PWRSW` | Power switch |
| `RSTSW` | Reset switch |
| `BIOS{QSPI SEL}` | BIOS flash select |

---

## MIDI Interface

The DIN ports are a **hardware UART**, jumper-routed to *either* the Teensy 4.1
*or* the LattePanda Mu — not both at once. This is independent of USB-MIDI:
`usbMIDI` and the DIN UART are separate transports, and any DIN↔USB merge has
to be done in firmware.

### Circuit

```
                              JMP1 "MIDIRX"            ┌─ pin 1 ─ Teensy IO34 (Serial8 RX)
MIDI IN  (J10, SDS-50J)           (select)             │
  pin 4 ─ R51 220R ─┐                                  │
                    ├─ H11L1 (U10) ─ MIDI.RX ─ pin 2 ──┤
  pin 5 ─ D17 ──────┘   opto, V3P3                     │
                                                       └─ pin 3 ─ LattePanda UART2_RXD (U1.140)

                              JMP2 "MIDITX"            ┌─ pin 1 ─ Teensy IO35 (Serial8 TX)
MIDI OUT (J11, SDS-50J)           (select)             │
  pin 5 ─ R52 10R ─┐                                   │
                   ├─ 74LVC1G17 (U28) ─ MIDI.TX ─ pin 2┤
  pin 4 ─ R53 33R ─┘   buffer, V3P3                    │
                                                       └─ pin 3 ─ LattePanda UART2_TXD (U1.138)
```

### Verified from Rev A0 netlist

**Routing jumpers — pin 2 is the common on both.** `JMP1` (`MIDIRX`) and
`JMP2` (`MIDITX`) are 3-pin `PH1-03-UA` headers, both populated:

| | pin 1 | pin 2 (common) | pin 3 |
|---|---|---|---|
| **JMP1** `MIDIRX` | `/Audio/MIDI.RX` → **Teensy `U9.26` = IO34** | `/MIDI/MIDI.RX` → `U10.4` opto output | `/Computer/AUDIO.MIDI.RX` → **Mu `U1.140` UART2_RXD** |
| **JMP2** `MIDITX` | `/Audio/MIDI.TX` → **Teensy `U9.27` = IO35** | `/MIDI/MIDI.TX` → `U28.2` buffer input | `/Computer/AUDIO.MIDI.TX` → **Mu `U1.138` UART2_TXD** |

- Shunt **1–2** on both → DIN MIDI serves the **Teensy**.
- Shunt **2–3** on both → DIN MIDI serves the **LattePanda Mu**.
- Mixing them (one jumper each way) gives the confusing half-working case:
  MIDI IN to one processor, MIDI OUT from the other.

**Teensy pins: `Serial8`.** `IO34` = RX, `IO35` = TX (symbol alternates
`UART8.RX` / `UART8.TX`). In Teensyduino: `Serial8.begin(31250)`, or
`MIDI_CREATE_INSTANCE(HardwareSerial, Serial8, MIDI)`.

**LattePanda pins:** `UART2` — `U1.140` RXD / `U1.138` TXD.

**MIDI IN (`J10`)** — opto-isolated per the MIDI spec:
DIN pin 4 → `R51` 220 Ω → `U10` (H11L1) LED anode; DIN pin 5 → `D17`
(reverse protection) → LED cathode. `U10` has a **push-pull Schmitt output**
on `V3P3`/`VSS`, so `MIDI.RX` is already clean logic — no external pull-up
needed and polarity is handled. Shield/GND via `R54` 0 Ω and `C85`/`C86`
100 pF.

**MIDI OUT (`J11`)** — buffered, 3.3 V current-limiting:
`MIDI.TX` → `U28` (74LVC1G17 Schmitt buffer, `V3P3`) → `R52` **10 Ω** →
DIN pin 5; `R53` **33 Ω** → DIN pin 4. These are the **3.3 V-scaled** MIDI
OUT values, *not* the classic 220 Ω / 220 Ω pair used on 5 V designs — do not
"correct" them to 220 Ω.

> **`R245` is a 0 Ω DNP bypass across `U28` (input `A` ↔ output `Y`), and DNP
> is the correct state.** It exists so the buffer can be bypassed if `U28` is
> depopulated. With `U28` fitted (as it is on Rev A0), `R245` must stay
> unpopulated — fitting it would short the buffer's input to its output.

**Domain:** MIDI lives in the **digital** domain (`V3P3` / `VSS`), *not* the
isolated audio domain. The opto on MIDI IN provides the MIDI-spec isolation
from the external cable, which is a separate concern from the `AVSS` audio
isolation barrier.

- **Connectors:** `J10` = MIDI **IN**, `J11` = MIDI **OUT**, both Same Sky
  SDS-50J 5-pin DIN (hand-soldered, DNP in the PCBA order)
- **Signals:** `MIDI.TX`, `MIDI.RX` (codec/DIN side), `AUDIO.MIDI.TX`,
  `AUDIO.MIDI.RX` (host side)

### Bring-up

1. Set `JMP1` and `JMP2` **both** to 1–2 for the Teensy.
2. Echo raw DIN bytes to the host to prove the path before writing parser code:

```cpp
void setup() { Serial8.begin(31250); }
void loop() {
  while (Serial8.available())
    usbMIDI.sendControlChange(9, Serial8.read() & 0x7F, 16);
}
```

If nothing arrives, check `JMP1` is on 1–2 before suspecting firmware.

---

## Display

- **Connector:** HDMI Type-A receptacle (J1, 19-pin)
- **Bus:** DDIB from LattePanda Mu
- **Signals:** 3 TMDS data pairs + 1 clock pair (differential)

| Signal | Description |
|---|---|
| `_HDMI.CLK+`, `_HDMI.CLK-` | Pixel clock (differential) |
| `_HDMI.D0+`, `_HDMI.D0-` | Data lane 0 |
| `_HDMI.D1+`, `_HDMI.D1-` | Data lane 1 |
| `_HDMI.D2+`, `_HDMI.D2-` | Data lane 2 |
| `DISABLE` | Display enable/disable control |

---

## Storage — M.2 Slots

### M.2 Key-M (J13)

- **Format:** M.2 2280 Key-M (NGFF)
- **Interface:** PCIe x4 via `PCIEP3{PCIE4X}`
- **Use:** NVMe SSD

### M.2 Key-A+E (J19)

- **Format:** M.2 2280 Key-A+E (NGFF)
- **Use:** WiFi/Bluetooth module or alternate storage
- **Selected module:** Intel AX210 (WiFi 6E tri-band + Bluetooth 5.3, M.2 2230 Key-E) — Amazon.ca

### Mounting Options

M2M42, M2AE30, M2M60, M2M80, M2M110 — supports multiple card lengths.

---

## Ethernet

- **Controllers:** 2× Realtek **RTL8111H-CG** (U7, U8) — PCIe Gigabit Ethernet controllers
- **Connectors:** 2× Amphenol **RJE58-188-5411** (J8, J9) — shielded 8P8C with dual LEDs (Yellow/Green), Cat5e (Mouser: 523-RJE58-188-5411). **As of 2026-05: 5411 backordered at Mouser CA — substitute with Amphenol RJE58-188-5441 (Mouser 523-RJE58-188-5441), same KK 254 family, same footprint, LEDs Green/Yellow (sides swapped from 5411).** KiCad footprint `reekilib_con:amphenol_RJE58-188-54x1-0x` accepts any RJE58-188-54x1 variant by design (`ki_fp_filters` allows the whole family).
- **Isolation transformers:** Würth 749020111A pulse transformers (T1, T2) on each port
- **Interface:** Each RTL8111H connects via PCIe x1 from LattePanda Mu
- **Use:** Dual Gigabit Ethernet — one for general network, one for dedicated audio/control (OSC, etc.)

---

## Main Encoder (E1)

- **Part:** Bourns PEL12T-4225T-S1024
- **Type:** 24-pulse/rev optical encoder + momentary push switch + RGB LED illumination
- **Resolution:** 24 PPR (96 edges/rev in quadrature)
- **Use:** Primary navigation/value encoder for the instrument UI
- **Connections:** Encoder A/B pulses → Management MCU GPIO; RGB LED → Management MCU PWM outputs; push switch → Management MCU GPIO

---

## Parts Not Assembled by PCBWay (DNP — Order Separately)

**Interactive BOM:** [hw/bom/ibom.html](hw/bom/ibom.html) — open in browser, click any designator to highlight on the PCB.

Connectors and footprints are on the PCB; the parts themselves must be hand-soldered. Quantities below are per board × 3 boards, and reflect the parts actually ordered for the Rev A0 build.

| # | BOM# | Per board | Part | BOM original | Installed | Source | Notes |
|---|---|---|---|---|---|---|---|
| 1 | 40 | 1 | **Encoder RGB+switch** (E1) | Bourns PEL12T-4225T-S1024 | same | Mouser 652-PEL12T4225TS1024 | 24 PPR, push, RGB |
| 2 | 47 | 2 | **XLR+TRS combo** (J4, J5) | Neutrik NCJ9FI-H-0 | same | Mouser 568-NCJ9FI-H-O | |
| 3 | 50 | 2 | **Ethernet RJ45** (J8, J9) | Amphenol RJE581885411 | **RJE58-188-5441** (5411 backordered) | Mouser 523-RJE58-188-5441 | 8P8C, dual LEDs (Green/Yellow), Cat5e, same KK254 footprint |
| 4 | 51 | 2 | **MIDI DIN** (J10, J11) | Same Sky SDS-50J | same | Mouser 490-SDS-50J | 5-pin DIN 180° |
| 5 | 52 | 1 | **Line out TRS** (J12) | Neutrik NSJ12HF-1 | same | Mouser 568-NSJ12HF-1 | 6.35mm stacking stereo |
| 6 | 55 | 2 | **GPIO pin header** (J15, J16) | Samtec MTSW-108-22-L-T-330-RA | **same** (MTSW-108, confirmed) | Samtec direct | 3×8 R/A 2.54mm. **The real 8-pos MTSW-108 was used — not the "cut-down MTSW-110" alternative.** |
| 7 | 56 | 2 | **Grove connectors** (J17, J18) | TE 2041145-4 | **TE 440055-4** | Mouser 571-440055-4 | HPI 2.0mm R/A THT, same family |
| 8 | 105 | 1 | **Headphone vol pot** (R273) | Bourns PTR902-2015K-B103 | **PTR902-2020K-A103** | Mouser 652-PTR902-2020KA103 | Audio taper, 20mm shaft |
| 9 | — | 1 | **OLED panel** (J25) | — | **REX012864AYAP3N00000** (primary) / MCOT128064B1V-WM (alt) | Mouser 668-REX012864AYAP3N / DigiKey #21322651 | Bare 24-pin FPC panel; J25 ZIF socket is PCBWay-assembled |
| 10 | — | 1 | **Teensy 4.1** (U9) | — | PJRC Teensy 4.1 (SparkFun DEV-20359 = headerless) | Mouser / PJRC / DigiKey | Footprint `reekilib_som:teensy_4.1`, 2.54 mm pitch THT, 24+24+5 pins |
| 10a | — | 2 | **Teensy long-row headers** | — | Samtec **TSW-124-07-T-S** | Mouser 200-TSW12407TS | 24-pin, 2.54 mm pitch, **2.54 mm insulator** (sets Teensy↔Pandore gap), direct-solder stack |
| 10b | — | 1 | **Teensy USB-host header** | — | Samtec **TSW-105-07-T-S** | Mouser 200-TSW10507TS | 5-pin, same family |
| 10c | — | 2 | **USB-D± pogo pins** (J28, J29) | — | Same Sky **CPG-23-SMT-TR** | Mouser 490-CPG-23-SMT-TR | **Spring contacts that tap Teensy's bottom-side USB-D+/D- pads** — NOT USB-C receptacles. Working height 2.50–2.90 mm (normal 2.70 mm), Ø1.80 pad / Ø1.35 hole, hand-soldered |
| 11 | — | 1 | **M.2 NVMe SSD** (J13) | — | User choice | — | Storage for host OS / samples |
| 12 | — | 1 | **M.2 WiFi/BT** (J19) | — | **Intel AX210** (WiFi 6E + BT 5.3) | Amazon.ca | |

---

## Expansion

### Extra Port Headers — AIO/DIO (J15, J16, DNP)

- **BOM part:** Samtec MTSW-108-22-L-T-330-RA (3×8, 2.54mm, right-angle, THT)
- **Alt:** MTSW-110-22-S-T-330-RA (10-pos) — cut to 8-pos before assembly
- **Footprint:** `reekilib_con:HDR254P3X8-THRA`
- **Ordered from:** Samtec direct (ships next day)
- **Power:** these headers carry the **`VRTIO`** rail, which in `pandore-rtmcu.kicad_sch` is a **plain wire straight to `V3P3`** (no regulator, no fuse, no series element) — i.e. 3.3V. Connected to the RTIO MCU (RP2350B).

### UART / I2C breakout headers (J33–J36, on-board)

- 1×3 headers in `pandore-extraport.kicad_sch`: **J34 = UART0, J33 = UART1, J35 = I2C3, J36 = I2C4** (LattePanda Mu buses).
- **No power pin** — each is GND + 2 signals only.

### Grove Connectors (J17, J18, DNP) — I2C sensor ports

- **BOM part:** TE Connectivity 2041145-4 (HPI 2.0mm, R/A, DIP, 4-pos)
- **Installed part:** TE 440055-4 — same AMP HPI 2.0mm family, same R/A through-hole form factor (Mouser: 571-440055-4)
- 4-pin Grove/HY2.0 compatible, wired for **I2C** sensor modules

**Verified electrical design (from `pandore-mgmtmcu.kicad_sch`, 2026-09):**

| Fact | Detail |
|---|---|
| **Voltage** | **3.3V ONLY.** The connector symbol's power pin is literally named `3.3V`, not `VCC` — this is a deliberately 3.3V-native port, not a mistake. |
| **No jumper** | There is **no jumper, 0Ω option, or unpopulated footprint** to switch Grove to 5V. Confirmed against all 13 board jumpers (JMP1–JMP15). To get 5V you must hardware-mod (lift a PTC output leg, jumper to V5) — and the signal pins still need level shifting because RP2350 GPIO is 3.3V-only, not 5V-tolerant. |
| **Power source** | V+ comes from **`VSTBY`** (always-on standby rail, ~3.3V from LDO U27 LDL212DR) through a per-port PTC fuse. **Not** a switched rail. |
| **PTC fuses** | J17 → PTC1, J18 → PTC2. Both **Bel Fuse 0ZCM0010FF2G: 0.1A hold, 6V max.** So each port is budgeted ~100 mA, shared with BIOS / boot control / CPU module / mgmt MCU on the same standby domain. |
| **Signal chain** | RP2350 mgmt-MCU GPIO → **R197** (560Ω quad series array, Panasonic EXB-28V561JX) → **D27** (ESD204DQAR TVS array, 5V clamp) → connector. |
| **No pull-ups on Pandore** | Bus pull-ups are expected on the sensor module (both Grove and Qwiic modules supply their own). |
| **Two independent I2C buses** | Grove **A (J17) = mgmt-MCU I2C0**; Grove **B (J18) = mgmt-MCU I2C1**. Not a shared bus. |
| **Pin mapping** | `PRIM = SCL`, `SEC = SDA`. (A: PRIM=I2C0.SCL/SEC=I2C0.SDA; B: PRIM=I2C1.SCL/SEC=I2C1.SDA.) Signal pins are the connector's D0/D1. |

> ⚠️ **560Ω series resistors constrain I2C pull-up sizing.** R197's 560Ω sits between MCU and connector. When the bus is pulled low, the MCU pin sees `560 × I_pullup` above ground; RP2350 V_IL ≈ 0.99V, so total parallel pull-up must stay **above ~2.4 kΩ**. A single SparkFun Qwiic board (2.2 kΩ pull-ups) is at the edge; two chained will break it. Adafruit STEMMA QT (10 kΩ) is safe. Remedy: cut pull-up jumpers on chained boards, or drop R197 to ~100Ω in rev A1. **Measure on the bench before committing.**

#### Sensor ecosystem — standardize on Qwiic / STEMMA QT

**Decision (2026-09): Qwiic / STEMMA QT / Arduino Modulino. Not M5Stack.**
The ports exist to give the average user an easy plug-in sensor solution, and the
3.3 V-only wiring above decides which ecosystem that can be.

| Ecosystem | Verdict |
|---|---|
| **Qwiic / STEMMA QT** | ✅ 3.3 V *by definition* — no level shifter, no rail change, no hazard. 400+ boards. Works on Rev A0 today via a Grove→Qwiic adapter cable (Adafruit #4528 / SparkFun PRT-15109 — I²C-only, which matches Pandore's Grove wiring exactly). |
| **Seeed Grove** | ⚠️ 5 V by default; only a ~60-module 3.3 V subset. Beware "3.3V/5V" on a datasheet — that is a *rated range*, and logic follows VCC. There is no jumper. |
| **M5Stack Units** | ❌ Need 5 V (onboard LDO per unit). Incompatible with a 3.3 V port. Only worth revisiting if the cased-unit aesthetic ever outweighs the 400-board catalogue — and that needs a 5 V-switchable port plus a PCA9306/TXS0102 translator per port. |

**Rev A0 bench plan:** order Grove→Qwiic cables plus a few Adafruit STEMMA QT /
Arduino Modulino modules; validate both the I²C path *and* the pull-up budget above.

**Rev A1 wishlist:** drop `R197` to ~100 Ω, and move Grove V+ off `VSTBY` onto a
**switched** 3.3 V rail — reuse the ET20162 load-switch pattern already used on every
USB VBUS. A chain of 8–10 sensors at 5–10 mA each lands right on the 100 mA PTC limit.

### Sensor ecosystem — use Qwiic / STEMMA QT (NOT M5Stack)

The Grove ports exist to give the average user an easy plug-in sensor solution. **Ecosystem research (2026-09) settled on Qwiic / STEMMA QT / Arduino Modulino, because they are 3.3V-native and match the port Pandore already has.**

**Why not the obvious Grove vendors:**

| Ecosystem | Verdict | Reason |
|---|---|---|
| **M5Stack Units** | ✗ Incompatible as-is | Grove port defined as **5V** power; most Units have an onboard 5V→3.3V LDO feeding the sensor die (e.g. ENV III's QMP6988 maxes at 3.6V). Won't get correct power from Pandore's 3.3V port. Nicely cased ($3–$33), but voltage often absent from their spec tables. |
| **Seeed Grove** | ~ Partial | Grove is **5V-default**; only a **~60-module subset** is 3.3V-safe (cf. Seeed's own 3.3V Grove Base Hat for Raspberry Pi, which documents the same limitation). "3.3V/5V" on a module = **rated supply range, logic follows VCC** — no jumper. Feeding 5V-logic modules 3.3V works for LDO/wide-Vin types but not all. |
| **Qwiic / STEMMA QT / Modulino** | ✓ **Recommended** | **3.3V by definition** (`GND / 3.3V / SDA / SCL`). Always 3.3V logic → **no level shifter, no rail change, no hazard.** I2C-only (no analog/UART ambiguity). 400+ boards across SparkFun (strict 3.3V), Adafruit (3–5V safe), Arduino Modulino (12 modules, C++ **and** MicroPython libs). Two connectors per board = daisy-chainable. |

**"3.3V/5V" mechanisms on dual-rated modules (why there's usually no jumper):**
1. **Wide-Vin chip, logic follows VCC** (e.g. Grove SHT31) — VCC feeds die directly; 5V VCC → 5V logic. *This is the 5V hazard on a shared port.*
2. **Onboard LDO** (e.g. Grove Digital Light XC6206, Human Presence XC6206) — self-regulates to 3.3V, logic always 3.3V. Safest.
3. **Solder pads** (rare, e.g. Grove Lightning AS3935) — bridge pads with iron. Fails the average-user test.

**Connector gap is a $2 cable, works on rev A0 today (unmodified):**
- Adafruit **#4528** — Grove to STEMMA QT / Qwiic / JST SH (100mm)
- SparkFun **PRT-15109** — Qwiic Cable, Grove Adapter (100mm)
- These adapters are **I2C-only** — which is exactly Pandore's Grove wiring. For rev A1, swap J17/J18 footprint to JST SH 1.0mm to make it native.

**Rev A1 recommendations (all verified against schematic):**
- Move Grove V+ off `VSTBY` to a **switched 3.3V** rail (a Qwiic chain of 8–10 sensors at 5–10 mA each lands right on the 100 mA PTC limit). The board already proves the **ETEK ET20162** load-switch pattern (U29–U33, 1A, used on all USB VBUS) — reuse it.
- Drop R197 from 560Ω to ~100Ω to widen the I2C pull-up budget.
- If M5Stack's cased-unit aesthetic is wanted later, that (and only that) justifies a 5V-switchable port **plus** a PCA9306/TXS0102 translator per port — but the 400-board Qwiic catalog with zero-risk wiring is the better default.

### Other

- **UARTDBG** — 3-pin serial debug header
- **USB-C overcurrent detection** (`USB_OC`)

---

## Bringup / Hand-Assembly (per Laurence's bringup doc)

Reference: [doc/test/bringup/pandore_a0_bringup.md](doc/test/bringup/pandore_a0_bringup.md) (commit `4497a3b`, 2026-05-19).

### Mechanical mounting stack-ups

| Mount | Screw | Standoff | Washer | Nut | Board-to-board gap | Notes |
|---|---|---|---|---|---|---|
| **PCB chassis mounts** (×8) | **M3** standard | — | — | — | n/a | `MNT1` is the chassis-ground anchor — populate `R1` + `C1` to connect VSS to chassis at single point |
| **LattePanda Mu** (×4) | **M2.5** machine screw | M2.5 × 5 mm threaded stackable standoff | M2.5 flat washer | M2.5 nut | **5.5 mm** | uxcell M2.5×5mm Male-Female standoff (Amazon); washer compresses ~0.3 mm under torque |
| **Teensy 4.1** (×0 mech, ×53 elec) | — | — | — | — | **~2.54 mm** | No mechanical screws — held entirely by Samtec TSW headers. **Insulator sets the gap.** CPG-23 pogo pins need 2.50–2.90 mm working height (normal 2.70) — TSW-124-07-T-S's 2.54 mm puts the pin near max compression, within spec but tight. Align pogo pins carefully before soldering. |
| **M.2 Key-AE** (WiFi/BT, ×1) | **M2** machine screw | M2 × 2.5 mm standoff (grind a 6 mm down) | — | M2 nut | **2.45 mm** | Heavy tools needed for the grind |
| **M.2 Key-M** (NVMe, ×1) | **M2** machine screw | M2 × 6 mm standoff | M2 flat washer | M2 nut | **6.65 mm** | Standoff body length + washer = ~6.3 mm; M.2 connector compliance absorbs the 0.35 mm |

### Hardware sourcing (Laurence's choices)

| Item | Source |
|---|---|
| M3 chassis screws | McMaster **92832A215** |
| M2.5 standoff/nut/screw kit | XLX assortment, Amazon CA (B07FMV5RMG) |
| M2 standoff/nut/screw kit | Emperoch kit, Amazon CA (B0G13683TS) |
| **M2.5 flat washer** (Mouser) | Essentra **16M02556080** — nylon, 2.7 mm ID / 5.6 mm OD / 0.8 mm thick, 1000-pack |
| **M2 flat washer** (Mouser) | Essentra **MFW010A** — nylon, ~2.2 mm ID / 5.0 mm OD / 0.3 mm thick, 1000-pack |
| Single M2.5 × 5 mm standoff (alt) | uxcell, Amazon CA (B08F21MDT8) |

### Other manual-assembly items

| Item | Part / Notes |
|---|---|
| RTC battery | CR2032 (any source, Amazon CA easy) |
| Manual jumpers (15 total: JMP1–JMP15) | Standard 2.54 mm jumper shunts. Two are easy to confuse: **JMP12 `AUTOON`** is the hardware auto-power-on (short it for boot-on-power); **JMP15 `PON`** is a 3-pin power-state select (S3/S0), not auto-power-on. Some need elongated shunts. |
| Encoder (E1) | Bourns PEL12T-4225T-S1024 — manually assembled (cost + sourcing) |
| Audio connectors | J4, J5 (XLR combo), J12 (TRS line out) — hand-soldered |
| Ethernet connectors | J8, J9 (RJE58-188-5441) — hand-soldered |
| RTIO connectors | J15, J16 — hand-soldered, **needs support during soldering** (header strongly overhangs PCB edge) |
| Teensy GPIO expansion | EXP10–EXP13 — hand-soldered |
| Fan headers | J27, J38 (Molex 47053-1000) — PCBWay-assembled, but fan cable's PC-fan plug needs cutting and re-terminating with KK 254 housing (22-01-3047) |

---

## Power Distribution

### Rails

| Rail | Voltage | Current | Purpose |
|---|---|---|---|
| `V12` | 12V | — | LattePanda Mu core |
| `V5` | 5V | **2A budgeted (10W); 3.5A silicon** | From buck U19 (AP63356Q, FB 158k/30k → 5.01V). Digital peripherals, USB VBUS (4 ports ×1A + Teensy 1A = 5A of switch capacity oversubscribing the rail), **fan headers** |
| `V3P3` | 3.3V | 3A budgeted (10W); 3.5A silicon | From buck U20 (AP63356Q, FB 93.1k/30k → 3.28V). MCUs, codec digital, I/O. Also feeds `VRTIO` (hard-wired to V3P3) on the GPIO headers |
| `AV5` | 5V | — | Analog audio supply |
| `AV3P3` | 3.3V | — | Analog audio supply |
| `VM2` | — | — | M.2 slot supply |
| `VMIDI` | — | — | MIDI interface supply |
| `VSTBY` | ~3.3V | — | Standby (from LDO U27 LDL212DR, Vo=3.3/Io=0.1A). Also feeds **Grove ports** J17/J18 via PTC1/PTC2. CR2032 backup. |
| `VCORE` | — | — | Core voltage |
| `48V Phantom` | 48V | 10 mA | Condenser microphone bias |

### Ground Domains

| Ground | Description |
|---|---|
| `VSS` | Primary digital ground |
| `AVSS` | Analog audio ground |
| `VSSISO` | Isolated analog ground |

### DC Input Jack

- **Part:** Same Sky **PJ-063BH** (right-angle through-hole DC barrel jack, schematic in `pandore-power`)
- **Center pin:** **Ø 2.5 mm** (NOT 2.1 mm) — accepts a **5.5 × 2.5 × 11 mm** plug, center positive
- **Ratings:** 24 VDC max, 8 A max, 30 mΩ contact resistance
- **PCB-assembled by PCBWay**

> ⚠️ **PSU compatibility:** Most consumer 12 V/5 A bricks use the **5.5 × 2.1 mm** plug (AAEON EP-PS12V5A60WFJ, Cicor SW3101F-C2, Phihong PPL65W-120, TT Powerpax PSAD65-12-B1). **These will not fit Pandore.** The 5 W/2.1 mm plug's center hole is smaller than PJ-063BH's 2.5 mm center pin.

### Recommended PSU

- **DFRobot FIT1021** (Mouser **426-FIT1021**) — 12 V / 5 A / 60 W wall adapter with **5.5 × 2.5 × 11 mm plug** and interchangeable US/EU/UK heads, ~$22 CAD. Designed by DFRobot as the official adapter for the LattePanda Mu — zero compatibility risk.
- Alternative (if FIT1021 unavailable): **Mean Well GST90A12-P1M** (Mouser 709-GST90A12-P1M, 12 V/6.67 A/80 W, 5.5 × 2.5 mm plug, IEC C14 — needs separate cord). The `-P1M` suffix in Mean Well's catalog = 5.5 × 2.5 mm plug; `-P1J` = wrong (2.1 mm).

### Power ICs (from BOM)

| Part | Designator | Type | Role |
|---|---|---|---|
| Diodes AP63356Q | U19, U20 | Synchronous buck, 3.5A | Main DC-DC regulators (V5, V3P3) |
| STM LDL212DR | U13, U14, U27 | Ultra-low-dropout LDO | Local clean supply rails |
| ETEK ET20162 | U29–U33 | 5.5V / 1A current-limit load switch × 5 | USB VBUS switching (U29–U32 = 4 USB-A ports; U33 = Teensy USB host). 1A is a **fixed** limit (no ILIM pin). |
| TI LM5158RTER | U21 | Flyback/boost controller | 48V phantom power supply |
| TI TPS7A4001DGNR | U22 | Ultra-low-noise 40V LDO | Post-regulation of 48V phantom rail |
| Murata NXE2S1212MC-R7 | U12 | **2W** isolated DC/DC, 12V→12V (167 mA) | Isolated 12V for audio analog domain — critical to 114 dB DR spec |

### Protection

- Reverse-polarity protection
- **USB VBUS:** overcurrent handled by the ETEK ET20162 load switches (U29–U33), 1A fixed limit each — **not** the PTC fuses
- **PTC fuses PTC1/PTC2** (Bel Fuse 0ZCM0010FF2G, 0.1A hold, 6V max) protect the **Grove ports** (J17/J18) on the `VSTBY` rail — *corrected: earlier docs said "on USB VBUS", which is wrong*
- Power sequencing managed by Management MCU (RP2350, U4)

### Boot Control

| Signal | Description |
|---|---|
| `~{USBBOOT}` | USB boot enable (active low) |
| `RSTSW` | Reset switch → Management MCU |
| `PWRSW` | Power switch → Management MCU |
| `STATE0`, `STATE3` | System state monitoring |
| `AUTOON` (JMP12) | **Hardware auto-power-on** (2-pin): pad 1 → Q12 drain, pad 2 → `PWRSW`. Shorted = Q12 pulses `PWR_BTN#` on power-up, the mechanism LattePanda's design guide recommends over the BIOS "Restore AC Power Loss" setting |
| `PON` (JMP15) | **Power-state select** (3-pin): `MGMTMON.S3` / `MGMTMON.PWR` / `MGMTMON.S0`. Ties the Mgmt-MCU power monitor line to S3 or S0. **Not** the auto-power-on jumper |
| `B1`, `B2` | Momentary tactical switches (reset/power) |

Power sequencing uses MOSFETs Q11, Q12, Q14, Q15 (MOSFET_EN-N).

---

## Thermal

- **Dual fan headers:** CPU fan (**J27**) + system fan (**J38**), each with PWM + tachometer
- **Fan header part:** Molex **47053-1000** — KK 254 (Mini-Latch), 2.54 mm pitch, 4-pin, vertical THT, friction lock. **PCBWay-assembled.**
- **Mating female (cable-side) — order if making custom fan cables:**
  - Housing: Molex **22-01-3047** (Mouser 538-22-01-3047) — 4-circuit KK 254 Mini-Latch™ housing
  - Crimp terminals: Molex **08-50-0114** (Mouser 538-08-50-0114) — 22–30 AWG, tin
- **Cable pinout — VERIFIED against `pandore-fan.kicad_sch` (2026-09):** pin 1 = GND, **pin 2 = V5 (5V, NOT 12V)**, pin 3 = Tach, pin 4 = PWM. Power is fed **directly from V5 with no load switch or fuse** between rail and header. J27 and J38 are wired identically.
  - ⚠️ **Correction:** earlier docs claimed "+12V (Yellow)" per the Intel 4-wire spec. **The schematic has no V12 anywhere in the fan sheet — it's 5V.** Consistent with the DFRobot FIT0981 being a 5V cooler. If you re-terminate a *12V PC fan* against the old note it will get 5V and barely spin.
- **Heatsink options:**
  - FIT0981 — Active cooler (fan + heatsink), **5V fan** — **ships with PC-fan plug; cut & re-terminate with 22-01-3047 to mate Pandore's KK 254**
  - FIT0982 — Thin passive heatsink
  - FIT0989 — Fanless heatsink
- **Fan control:** driven by the **LattePanda Mu's native `FAN_CTL`/`FAN_TAC` pins** (`pandore-cpumod.kicad_sch`), i.e. BIOS/OS thermal management — *not* the Management MCU. Verified from the netlist 2026-09 and confirmed by Laurence.
- **Fan rail is +5 V, not +12 V.** The `VDD` net on `pandore-fan.kicad_sch` resolves to `V5`, matching DFRobot's Lite Carrier (`+5V_FAN`). A 12 V PC fan will spin at ~30 % and will not be damaged, but do not bodge 12 V onto pin 2.
- **Cable pinout (Intel 4-wire):** 1 = GND (black), 2 = +5 V, 3 = TACH, 4 = PWM. TACH inputs are **5 V tolerant only**; the Mu has internal pull-ups, so no external resistors are needed.

---

## PCB Specifications

| Parameter | Value |
|---|---|
| Dimensions | 260 mm × 110 mm |
| Layers | 4 (F.Cu / In1 / In2 / B.Cu) |
| Total components | 804 (480 front, 324 back) |
| SMD components | 700 |
| Through-hole | 83 |
| Unique parts | 141 |
| Total pads | 3,161 (2,702 SMD + 459 TH) |
| Vias | 2,217 |
| Drill holes | 2,439 |

---

## Repository Structure

```
pandore/
  AUDIO_PERFORMANCE.md   Audio specs (separate GitHub page)
  README.md              Project overview
  hw/                    Schematics (.kicad_sch) and PCB layout (.kicad_pcb)
  doc/
    arch/                Architecture diagrams (draw.io)
    img/                 Board renders
    reference/           Datasheets, app notes, design guides (PDF)
  lib/                   3D models (.step), KiCad symbols and footprints
  release/               Manufacturing artifacts (Gerbers, BOM, placement, 3D)
```

---

## Schematic Hierarchy

Top-level: `pandore.kicad_sch` → 24 sub-sheets:

**Audio (9 sheets):**
`audio`, `audio-codec`, `audio-inputs`, `audio-inbuf`, `audio-outputs`, `audio-outbuf`, `audio-isolation`, `audio-monitor`, `audio-power`

**Compute (5 sheets):**
`computer`, `cpumod` (LattePanda Mu), `mcu` (RP2350B RTIO), `mgmtmcu` (Management), `rtmcu`

**Power (2 sheets):**
`power`, `audio-power`

**Interface (6 sheets):**
`eth`, `usbport`, `midi`, `display`, `extraport`, `mdot2`

**System (3 sheets):**
`bootctl`, `bios`, `fan`

---

## Component Library

All schematics use the `reekilib` custom symbol/footprint library.

**3D Models (in `lib/`):**
- `LattePanda_Mu.step` — SBC module
- `LattePanda_Mu_H8.0_Horizontal.step` — Horizontal variant (8 mm clearance)
- `FIT0981_Active_cooler.STEP` — Active heatsink/fan
- `FIT0982-Thin-Heatsink.step` — Thin passive heatsink
- `FIT0989-Fanless-Heatsink.step` — Fanless heatsink

**KiCad Libraries:**
- `MCU_Module_LattePanda.kicad_sym` — LattePanda symbol
- `Module_LattePanda.pretty/` — LattePanda footprints (4 mm and 8 mm variants)

---

## Reference Documentation (`doc/reference/`)

| Document | Topic |
|---|---|
| RP2350 datasheet | MCU pinout, peripherals, electrical specs |
| Hardware design with RP2350 | PCB layout guidelines, decoupling, routing |
| LattePanda Mu EVA guide | Module pinout, power requirements, I/O mapping |
| Lite Carrier for LattePanda Mu (V2) | Carrier board reference design |
| CS4272 (via SuperAudioBoard docs) | Codec configuration, I2S timing, register map |
| THAT1512 gain configuration (DN138) | Reference design (not used in final BOM) |
| AES129 Designing Mic Preamps | Preamp circuit topology |
| Phantom power (SBOA320A) | 48V phantom PSU with op-amp |
| Ultra-low noise 48V phantom (RAQ-176) | Low-noise phantom supply design |
| Analog Secrets / More Analog Secrets | Analog design best practices |
| `thatmicpre/` (git submodule) | THAT Corp mic preamp reference designs |
| V50 regulator design (WBDesign) | 5V regulator design reference |

---

## Development Notes

### Firmware Targets

See [Software & Firmware Development → Firmware targets](#firmware-targets-recap) for the four targets, the repo, the verified toolchain, pin maps, and the wire protocol.

### Key Design Decisions

- **I2S isolation** prevents digital noise from corrupting audio — the audio domain has separate power (AV3P3/AV5) and ground (AVSS/VSSISO)
- **Teensy 4.1 as bridge** rather than direct I2S to LattePanda Mu — enables class-compliant USB Audio without custom x86 drivers
- **Dual RP2350** separates real-time I/O (latency-critical) from management (power, thermal, boot) — prevents priority inversion
- **48V phantom** is ultra-low-noise by design — critical for condenser microphone sensitivity
- **M.2 Key-M on PCIe x4** — full NVMe bandwidth for recording/sample playback

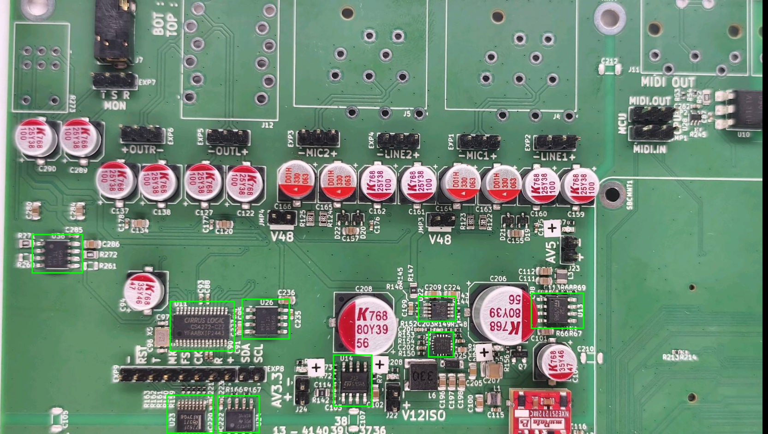
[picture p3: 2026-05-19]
doc/review/pandore-audio-top-review.png

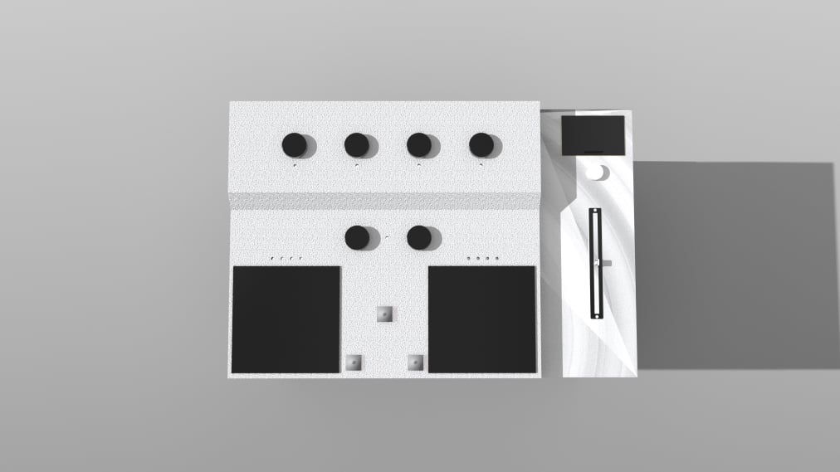
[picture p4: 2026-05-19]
doc/case+inst_v2_top.jpg

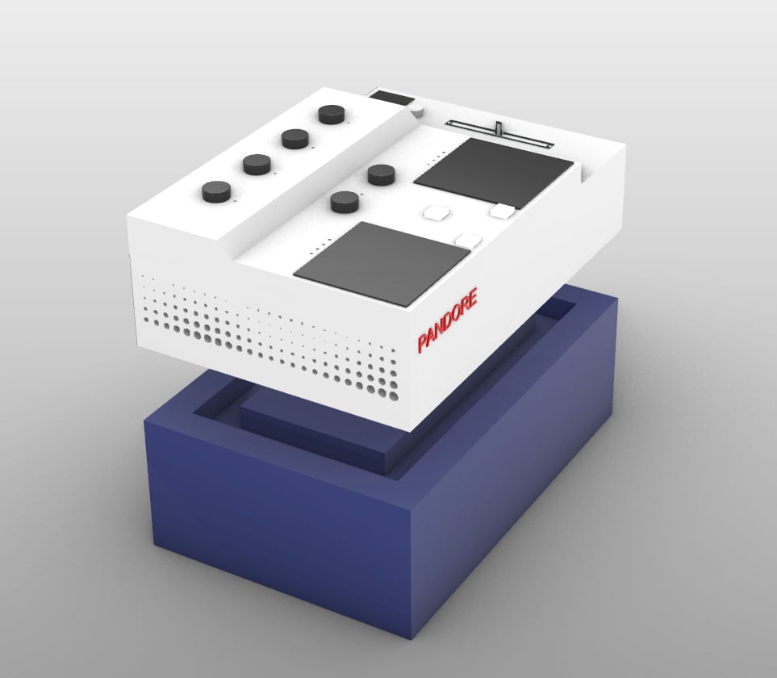
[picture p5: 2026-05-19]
doc/case+inst_v2_side.jpg

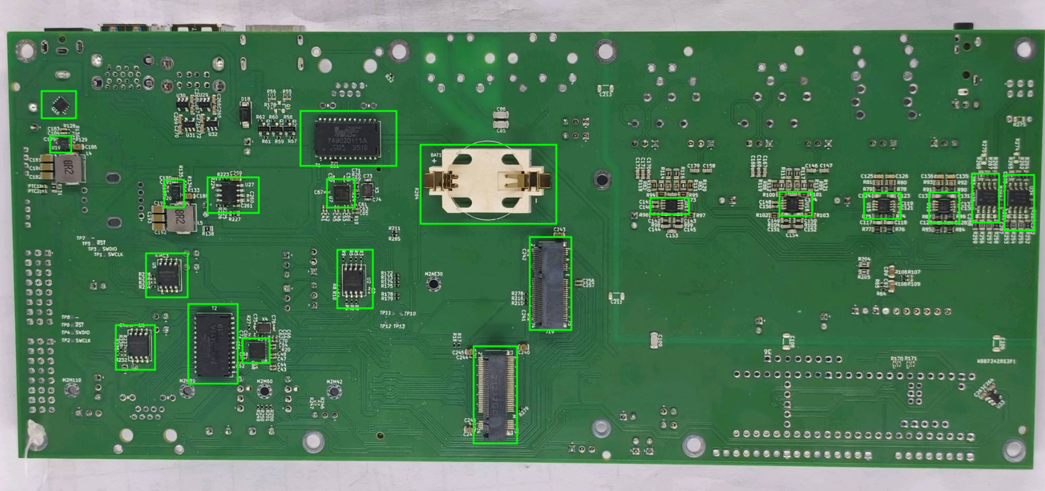
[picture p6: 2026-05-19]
doc/review/pandore-bot-review.png

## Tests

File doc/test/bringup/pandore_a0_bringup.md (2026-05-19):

# Pandore A0 bring-up

- [Pandore A0 bring-up](#pandore-a0-bring-up)
  - [Manual Assembly](#manual-assembly)
    - [Mounts \& Mechanic](#mounts--mechanic)
      - [Mounting PCB itself](#mounting-pcb-itself)
      - [SBC - LattePanda mu](#sbc---lattepanda-mu)
      - [Teensy](#teensy)
      - [M.2 key AE](#m2-key-ae)
      - [M.2 key M](#m2-key-m)
    - [Jumpers](#jumpers)
      - [Manual jumper](#manual-jumper)
      - [Chassis connection](#chassis-connection)
    - [Battery](#battery)
    - [Encoder](#encoder)
    - [Connectors](#connectors)
      - [Audio connectors](#audio-connectors)
      - [Ethernet connectors](#ethernet-connectors)
      - [RTIO connectos](#rtio-connectos)
      - [Teensy GPIO expansion](#teensy-gpio-expansion)
  - [Testing](#testing)
    - [Process](#process)
    - [Goals](#goals)
    - [Results](#results)

## Manual Assembly

### Mounts & Mechanic

#### Mounting PCB itself

All **8** PCB mounts are [M3 standard screws][m3_screw_link] and standoff, they are open to many final integration mounting scheme, the board itself should be rigid enough for usage on a desk or semi fixed setup

> Note: only `MNT1` is electrically connected to chassis (the actual electrical connection is not [mounted by default](#chassis-connection))

#### SBC - LattePanda mu

- distance between boards: 5.5mm
- screw type: M2.5

A [M2.5 kit][m25_kit_link] for the nut and screw is the easiest for low-volume

requires 2 mounting stack:

- 1× [threaded stackable standoff M2.5 5mm][m25_standoff_link]
- 1× threaded nut M2.5
- 1× machine screw M2.5
- 1× flat washer M2.5

#### Teensy

- distance between boards: ~2.5mm

The **2** chosen [pogo pin][pogo_pin_link] for USB contact have a working range of [2.5 : 2.9]mm, care should be taken to correctly align those 2 spring contact before soldering down the teensy module

#### M.2 key AE

- distance between boards: 2.45mm
- screw type: M2

requires 1 mounting stack:

- 1× threaded stackable standoff M2 2.5mm (NOT in common kits, ground down a 6mm down to ~2.5mm)
- 1× threaded nut M2
- 1× machine screw M2

> NOTE: This requires heavy tools

#### M.2 key M

- distance between boards: 6.65mm
- screw type: M2

a [kit of M2 standoff][m2_kit_link] and [washers][m2_washer_kit_link] is the easiest approach for low-volume

requires 1 mounting stack:

- 1× threaded stackable standoff M2 6mm
- 1× threaded nut M2
- 1× machine screw M2
- 1× flat washer M2

### Jumpers

#### Manual jumper

A total of **15** manual jumper exist on the board, they all require an additional jumper to be added: [Elongated][jumper_header_long_link], [normal][jumper_header_link]  
The jumper list : JMP1 - JMP15

#### Chassis connection

To connect `VSS` to the chassis the single point of contact should be `MNT1` and `R1`, `C1` should be assembled on the board (see [BOM](/release/pandore_2026-03-19_A0_release.zip) for actual component).  
The connection is intended to be easy to adapt the actual impedance to chassis desired and to channel all currents into a single point of reference.

### Battery

Requires a [CR2032][cr2032_link] to be installed in the socket

### Encoder

Manual assembly of the encoder was chosen to reduce assembly cost and ease sourcing of the exact desired encoder

### Connectors

#### Audio connectors

J4, J5, J12 requires manual assembly

#### Ethernet connectors

J8, J9 requires manual assembly

#### RTIO connectos

J15, J16 requires manual assembly, supports for it during soldering needs to be taken into consideration as it is strongly overhanging outside the PCB.

#### Teensy GPIO expansion

EXP10 - 13 requires manual assembly

---

## Testing

### Process

### Goals

### Results

<!-- link -->

[m3_screw_link]: https://www.mcmaster.com/92832A215/
[jumper_header_link]: https://www.amazon.ca/Gikfun-Micro-Jumper-Arduino-EK1025C/dp/B06XGSZ91M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
[jumper_header_long_link]: https://www.amazon.ca/uxcell-2-54mm-Lengthened-Circuit-Connection/dp/B08Y7YJGL1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
[m2_kit_link]: https://www.amazon.ca/Emperoch-Spacers-Standoff-Circuit-Computer/dp/B0G13683TS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
[m2_washer_kit_link]: https://www.amazon.ca/Emperoch-Spacers-Standoff-Circuit-Computer/dp/B0G13683TS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
[pogo_pin_link]: https://www.sameskydevices.com/product/interconnect/connectors/pogo-pins/cpg-23-smt-tr
[m25_standoff_link]: https://www.amazon.ca/uxcell-M2-5x5mm-Male-Female-Motherboard-Quadcopter/dp/B08F21MDT8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
[m25_kit_link]: https://www.amazon.ca/XLX-Male-Female-Female-Female-Assortment-Stainless/dp/B07FMV5RMG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
[cr2032_link]: https://www.amazon.ca/s?k=CR2032&crid=19SXD1OPVG0N3&sprefix=cr2032%2Caps%2C226&ref=nb_sb_noss_1

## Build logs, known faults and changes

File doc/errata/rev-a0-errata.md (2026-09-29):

# Pandore Rev A0 — Errata

Known hardware issues in revision A0. Each entry records the symptom, the
evidence it was confirmed from, any workaround, and the fix for the next
revision.

| ID | Subsystem | Severity | Status |
|----|---|---|---|
| [ERR-001](#err-001--cs4272-i²c-sdascl-crossed-between-isolator-and-codec) | Audio / codec control | **Blocking** — codec unreachable over I²C | Open, software workaround available |
| [ERR-002](#err-002--teensycodec-i²s-signals-rotated-across-the-isolator) | Audio / I²S data path | **Blocking** — no audio in either direction | Open, hardware rework required |
| [ERR-003](#err-003--rj45-jacks-split-the-two-middle-ethernet-pairs) | Ethernet / both ports | **Degraded** — links fall back to 100 Mbit/s | Open, adapter patch cord restores gigabit |
| [ERR-004](#err-004--ethernet-controllers-have-no-mac-address) | Ethernet / both ports | **Minor** — random MAC address at every boot | Open, software workaround in place |

---

## ERR-001 — CS4272 I²C SDA/SCL crossed between isolator and codec

**Subsystem:** Audio — codec control port
**Severity:** Blocking. The CS4272 cannot be configured over I²C at all.
**Affects:** Revision A0, all three boards.
**Status:** Open, root cause **confirmed by the designer** (Laurence, 2026-09-02).
Software workaround available for the Teensy; no rework required for it.
**The host path is not equally recoverable** - see "Effect on the LattePanda Mu" below.

### Symptom

The Teensy 4.1 never detects the CS4272. Any I²C transaction to address
`0x10` fails to receive an ACK — `Wire.endTransmission()` returns non-zero,
an address scan finds nothing at `0x10`, and firmware that gates on codec
presence takes its "codec absent" path.

Because the codec is never taken out of power-down and never configured,
there is no I²S audio in either direction, even though the I²S clock and
data lines themselves are wired correctly.

### Root cause

`SDA` and `SCL` are transposed on the isolated (codec) side of the
`ISO1640BDR` I²C isolator (`U24`). The isolator's `SDA2` output lands on
the codec's `SCL` pin, and `SCL2` lands on the codec's `SDA` pin:

```
Teensy IO18 (SDA) ─ AUDMST.SDA ─ U24.2 SDA1 ─[ISO1640]─ U24.7 SDA2 ─ CTL.SDA ─ U11 pin 11 = SCL   <-- wrong
Teensy IO19 (SCL) ─ AUDMST.SCL ─ U24.3 SCL1 ─[ISO1640]─ U24.6 SCL2 ─ CTL.SCL ─ U11 pin 12 = SDA   <-- wrong
```

The net *names* (`CTL.SDA`, `CTL.SCL`) are correct with respect to the
isolator, which is why the error is easy to miss reading the schematic —
the mistake is in which codec pin each net attaches to.

The host side of the isolator is correct: `AUDMST.SDA` → `SDA1`,
`AUDMST.SCL` → `SCL1`. The LattePanda Mu's `I2C2` (`U1.156` / `U1.154`)
shares this bus and is likewise correct up to the isolator. Only the
codec-side attachment is transposed.

### Evidence

Confirmed from the Rev A0 netlist, cross-checked against an independent
CS4272 reference design.

Net membership, from `hw/pandore.kicad_pcb` per-pad net assignments:

| Net | Nodes |
|---|---|
| `/Audio/CODEC/CTL.SDA` | `U24.7 (SDA2)`, **`U11.11 (SCL)`**, `EXP8.2`, `R166` (2.2 kΩ pull-up) |
| `/Audio/CODEC/CTL.SCL` | `U24.6 (SCL2)`, **`U11.12 (SDA)`**, `EXP8.1`, `R167` (2.2 kΩ pull-up) |
| `/Audio/AUDMST.SDA` | `U9.40 (Teensy I2C0.SDA = IO18)`, `U24.2 (SDA1)`, `U1.156`, `R164` |
| `/Audio/AUDMST.SCL` | `U9.41 (Teensy I2C0.SCL = IO19)`, `U24.3 (SCL1)`, `U1.154`, `R165` |

CS4272 pinout verified independently of the project's own symbol library,
from `doc/reference/SuperAudioBoard_Schematic.pdf` (RF William Hollender,
a separate CS4272 design):

```
SCL | 11        AD0   | 13
SDA | 12        RST_N | 14
```

This matches the `reekilib` symbol's pin functions, so both the CS4272 and
ISO1640 symbols are correct — the error is in the connections, not the
library.

> **Confirmed by the board's designer.** Laurence Deschênes Villeneuve
> confirmed on 2026-09-02 that the CS4272's SDA and SCL pins were
> transposed in the Rev A0 design. This entry is therefore no longer a
> netlist-derived hypothesis: the root cause is established.
>
> A bench check is still worth doing once before rework, to confirm the
> board matches the design: probe `EXP8` pins 1 and 2 while the Teensy runs
> an I²C scan. The pin carrying the clock square wave should be the one
> routed to codec pin 12.

### Effect on the LattePanda Mu (host) path

`AUDMST` is shared: the Mu's `I2C2` (`U1.154` / `U1.156`) sits on the same
segment as the Teensy, and both cross `U24` to reach the codec. So the
transposition affects the host exactly as it affects the Teensy.

The difference is what each can do about it:

- **Teensy:** bit-bangs the bus, so it can simply swap the pin roles in
  software (Workaround A). No rework.
- **LattePanda Mu:** if it drives the codec through the **SerialIO I2C2
  hardware controller**, the roles cannot be swapped. A hardware I²C master
  will not work with SCL and SDA exchanged. The host would need either the
  hardware bodge (Workaround B), or to drive those two pins as GPIO and
  bit-bang (`i2c-gpio` on Linux), which depends on the pins being exposed
  as GPIO rather than owned by the I2C2 controller.

**Consequence for the BIOS request:** item 3.1.5 (release `I2C2` from its
PD-controller reservation) is still worth asking for, and remains a
one-shot opportunity, but on Rev A0 it will not by itself give the host a
working codec link. Do not report a failed host-to-codec I²C test to
LattePanda as a BIOS fault; it is this errata. (The BIOS customization
request itself lives in the private software repo, not here.)

### Workaround A — software, no rework (recommended)

`U24` is an **ISO1640BDR**, which is bidirectional on *both* channels
(unlike the ISO1641, whose SCL is unidirectional). It passes logic levels
without interpreting the protocol, so it does not care which line carries
clock and which carries data.

On this board, physically:

- **Teensy `IO18` reaches the codec's SCL**
- **Teensy `IO19` reaches the codec's SDA**

A bit-banged I²C master with the pin roles reversed (`SCL = 18`,
`SDA = 19`) therefore talks to the codec correctly with no hardware
change. The Teensy 4.1's LPI2C pin mux fixes `Wire` to `18 = SDA` /
`19 = SCL`, so the stock `Wire` library cannot express the swap; a
software I²C implementation that takes explicit pins can.

Pull-ups are already present on both sides of the isolator (`R164`/`R165`
host side, `R166`/`R167` codec side, 2.2 kΩ), so no additional components
are needed. Drive the lines open-drain only — pull low, release high,
never drive high — as the isolator requires.

### Workaround B — hardware bodge

`EXP8` is a populated 2-pin header (`PH1-02-UA`, labelled `I2C`) sitting
directly on `CTL.SDA` (pin 2) and `CTL.SCL` (pin 1) — the codec side of
the isolator. It is the most accessible point on the two affected nets, so
cutting the two traces and cross-strapping at `EXP8` is preferable to
scraping traces at the codec's fine-pitch package.

Only do this if the software workaround is unsuitable; it permanently
diverges the board from the schematic.

### Fix for Rev B

In `hw/pandore-audio-isolation.kicad_sch` / `hw/pandore-audio-codec.kicad_sch`,
swap the codec-side attachment so that:

- `CTL.SCL` (isolator `SCL2`) connects to `U11` pin **11** (SCL)
- `CTL.SDA` (isolator `SDA2`) connects to `U11` pin **12** (SDA)

Add an ERC/review check that each I²C net terminates on a pin of matching
function at both ends. The net names were correct throughout, so a
name-based review would not have caught this — the check has to compare
against pin function.

---

## ERR-002 — Teensy↔codec I²S signals rotated across the isolator

**Subsystem:** Audio — I²S data path (MCU ↔ codec)
**Severity:** Blocking. No audio can pass in either direction — playback *or* capture.
**Affects:** Revision A0 (schematic-level — every board).
**Status:** Open. No software workaround; hardware rework required.

### Symptom

The line-out is silent and capture returns garbage, while the codec itself
measures completely healthy: it is detected and configured over I²C, runs as
I²S/clock master off its 24.576 MHz crystal at exactly 48 kHz, its references
are correct, and its output amplifiers are enabled.

### Root cause

The I²S signals between the Teensy (`U9`) and the CS4272 (`U11`) cross the
`ISO7762` isolator (`U23`, hex unidirectional 4:2) through four 0 Ω quad arrays
(`R168`, `R169`, `R170`, `R171` — Yageo `YC124-JR-070RL`). The YC124 pairs its
elements **1↔8, 2↔7, 3↔6, 4↔5**, and the connections were made as though the
ordering were different, so the signal assignment comes out rotated:

| Teensy pin | Actually connected to | Should be | |
|---|---|---|---|
| IO21 (BCLK in) | codec **MCLK** (24.576 MHz) | codec SCLK | ✗ |
| IO20 (LRCK in) | codec **LRCK** | codec LRCK | ✓ |
| IO8 (RX data in)  | codec **SCLK** | codec SDOUT | ✗ |
| IO7 (TX data out) | codec **SDOUT** (output↔output) | → codec SDIN  | ✗ |
| IO23 (MCLK) | drives codec **SDIN** | codec MCLK in | ✗ |
| IO22 (~RST) | codec ~RST | codec ~RST | ✓ |

Only **LRCK** and **~RST** land correctly. Two consequences are independently
fatal: the Teensy's audio output (`IO7`) is tied to the codec's `SDOUT` — an
output driving an output, with no path to `SDIN` — and the codec's `SDIN` is
instead driven from the Teensy's `MCLK` pin, which the audio library never even
configures in slave mode, so it sits high-impedance and `SDIN` is static.

The isolator channel *directions* are right for a codec-master board: `ISO7762`
provides four channels codec→MCU (`A`–`D`: SDOUT, SCLK, LRCK, MCLK) plus two
MCU→codec (`E`, `F`). `F` correctly carries `~RST`. `E` is the one channel that
should carry playback data to `SDIN`, and it is fed from the wrong Teensy pin.

### Evidence

- **The codec reports it is receiving nothing.** With Auto-Mute enabled
  (`reg 02h` bit 7) the CS4272 drives MUTEC active after 8192 consecutive zero
  samples and releases it on a single non-zero sample (datasheet §5.5). MUTEC
  gates the THS4521 output amplifiers, so the amps audibly drop in and out with
  real data. They never changed state regardless of signal — `SDIN` is
  permanently static.
- **Capture proves which signal is on the data pin.** A recording contains only
  the constant value `0x1E1E` — a repeating 4-high/4-low bit pattern. That is a
  square wave sampled at an exact **8:1** ratio, i.e. a **3.072 MHz SCLK**
  latched by a **24.576 MHz** bit clock (24.576 / 3.072 = 8). The Teensy's bit
  clock is the codec's MCLK and its data pin carries the codec's SCLK.
- **The frame rate is nevertheless correct** — firmware block-rate measurement
  reads exactly **48000 Hz**, because LRCK is the one clock wired correctly.
  This also confirms the YC124 1↔8/2↔7/3↔6/4↔5 pairing: the alternative pairing
  cannot produce either the 48 kHz frame rate or the 8:1 pattern.
- **Direct measurement of each pin, independent of all of the above.** The
  `audio/bringup/i2s_pinprobe` sketch (software repo) uses no Audio library and
  makes no assumption about the codec beyond putting it in master mode; it just
  counts GPIO edges. Measured with the codec free-running:

  | Teensy pin | measured | correct wiring would give |
  |------------|----------|---------------------------|
  | IO21 (BCLK in)    | ~24.576 MHz (at sampler limit) | 3.072 MHz |
  | IO20 (LRCK in)    | 48.0 kHz exactly               | 48 kHz ✓ |
  | IO8 (RX data in)  | 3072.2 kHz — a clean clock     | aperiodic data |
  | IO7 (TX data out) | 200-330 kHz, varying           | idle |
  | IO23 (MCLK in)    | 0 Hz — dead                    | 24.576 MHz |

  `3072.2 kHz` is 64 x 48000 to four digits and IO20 is exact, so the
  measurement is sound. IO7 varying run to run is data, not a clock.

Healthy and ruled out along the way: I²C configuration and register readback;
codec master-mode clocking from crystal `X5`; `FILT+` = 4.9 V (≈VA) and `VQ` =
2.5 V (≈VA/2); `VCMMON` = 2.5 V; MUTEC polarity and the THS4521 `PD` wiring,
which are **correct** (MUTEC is active-low per datasheet §5.5/§8.5.1). Note that
`chip ID` register `08h` reading `0x00` is normal for the CS4272.

### Workaround — none in software

Not because remapping is impossible in general. The IMXRT does provide
daisy-chain `SELECT_INPUT` registers for `SAI1_RX_BCLK`, `RX_SYNC` and
`RX_DATA0`–`3`, and SAI1's data lines can be assigned to several pads. The
problem is that none of the reachable pads are the ones this board uses. On
Teensy 4 (`__IMXRT1062__`), from the Audio library's own multi-channel objects:

| SAI1 signal | pads it can use | this board delivers it on | |
|---|---|---|---|
| TX_DATA | 6, 7, 9, 32 | codec `SDIN` driven from **IO23**  | ✗ |
| RX_DATA | 6, 8, 9, 32 | codec `SDOUT` arrives on **IO7** | ✗ |
| RX_BCLK | 21 only | codec `SCLK` arrives on **IO8** | ✗ |
| RX_SYNC (LRCK) | 20 only | codec `LRCK` arrives on IO20 | ✓ |

The hardest blocker is playback data: the codec's `SDIN` is fed from **IO23**,
which is SAI1's **MCLK** pad and carries no TX_DATA function at all, so audio
data cannot leave the chip on that pin by any SAI configuration. `SAI2` is no
alternative either — it is on pins 2/3/4/5/33, none of which this board uses.

The one theoretical escape is **FlexIO** (`IO23` = `AD_B1_09` has a FlexIO2
alternate): a FlexIO shift register clocked from the external BCLK/LRCK could in
principle emit the data, with the same required on the receive side. That means
writing a FlexIO-based I²S engine rather than remapping the SAI, and the Teensy
Audio library offers no such path — far more effort than lifting two 0 Ω arrays.

### Hardware bodge

`R168` and `R169` are **0 Ω** arrays, so removing them cleanly breaks every
incorrect connection at once and leaves accessible pads to jumper from. Lift
both, then wire six links:

```
U23 OUTA (codec SDOUT) -> Teensy IO8    (RX data)
U23 OUTB (codec SCLK)  -> Teensy IO21   (BCLK)
U23 OUTC (codec LRCK)  -> Teensy IO20   (LRCK)
U23 OUTD (codec MCLK)  -> Teensy IO23   (MCLK, optional in slave mode)
Teensy IO7 (TX data)   -> U23 INE       (-> OUTE -> R163 -> codec SDIN)
Teensy IO22 (~RST)     -> U23 INF       (already correct — keep)
```

This is preferable to cutting traces or lifting the codec's 0.65 mm pins: the
array pads are larger and every wrong net is removed in one step.

The Teensy IO numbers above were checked against the `U9` symbol rather than
assumed. The symbol numbers its pins in physical pad order and names most of
them `IOxx`, so the audio pins — which are named by function instead — are
pinned down by their explicitly numbered neighbours:

```
pin  8 = IO6           <- anchor        pin 39 = IO17          <- anchor
pin  9 = AUDIO.O1A     => IO7           pin 40 = I2C0.SDA      => IO18
pin 10 = AUDIO.IN1     => IO8           pin 41 = I2C0.SCL      => IO19
pin 11 = IO9           <- anchor        pin 42 = AUDIO.LRC1    => IO20
                                        pin 43 = AUDIO.BCL1    => IO21
                                        pin 44 = IO22          <- anchor
                                        pin 45 = AUDIO.MCL1    => IO23
                                        pin 46 = 3.3V          <- run ends
```

`IO22` at pin 44 falls *inside* the second run, so that sequence is anchored
from both directions. The same argument gives `UART8.RX`/`TX` at pins 26/27 as
`IO34`/`IO35` (between `IO33` at 25 and `IO36` at 28), which is the DIN MIDI
pair. This is also consistent with the `i2s_pinprobe` measurements, which landed
on exactly the pins this mapping predicts.

### Fix for Rev B

Re-map the isolator connections against the **YC124 1↔8 / 2↔7 / 3↔6 / 4↔5**
element pairing, and route the Teensy's I²S **TX data** (not its MCLK) into the
MCU→codec channel that feeds `SDIN`.

As with ERR-001 the net names all read plausibly, so a name-based review does not
catch this. The check has to verify, per net, that the *pin function* at each end
matches **and** that signal direction is consistent with the isolator channel
direction — here an output (`IO7`) was connected to a channel output, which an
ERC configured for pin-type conflicts across the array would have flagged.

---

## ERR-003 — RJ45 jacks split the two middle Ethernet pairs

**Subsystem:** Ethernet — both ports (`J8` "Internal Ethernet", `J9` "External Ethernet")
**Severity:** Degraded. Both ports work, but gigabit links fall back to 100 Mbit/s.
**Affects:** Revision A0. Observed on two boards (`pandore16`, `flou`).
**Status:** Open, root cause **confirmed on the bench** (2026-09-29): an adapter
patch cord that follows the board's pairing brings the link up at 1 Gbit/s.

### Symptom

Every link negotiates 100 Mbit/s, never 1000, whatever the other end. Against a
gigabit switch, Linux logs a downshift:

```
Generic FE-GE Realtek PHY r8169-0-200:00: Downshift occurred from negotiated speed 1Gbps to actual speed 100Mbps, check cabling!
r8169 0000:02:00.0 enp2s0: Link is Up - 100Mbps/Full (downshifted) - flow control rx/tx
```

### Root cause

The jack contacts are wired to the four signal pairs in numeric order. A cable
twists contacts **1-2, 3-6, 4-5 and 7-8** together (TIA-568), so the two middle
pairs each run over wires from two different twisted pairs:

| Signal pair | Jack pads (J8 and J9) | Twisted pair in the cable | |
|---|---|---|---|
| `PAIR0` (MDI0) | 1-2 | 1-2 | correct |
| `PAIR1` (MDI1) | **3-4** | 3-6 | split |
| `PAIR2` (MDI2) | **5-6** | 4-5 | split |
| `PAIR3` (MDI3) | 7-8 | 7-8 | correct |

100BASE-TX uses only contacts 1-2 and 3-6, and a split pair still gets through
on a short cable. 1000BASE-T drives all four pairs at once and fails; the PHY
retries, then downshifts to 100 Mbit/s.

Everything upstream of the jacks is correct: each port is an `RTL8111H`
(`pandore-eth` sheet) with a four-channel pulse transformer and all four pairs
routed (`MDI0`–`MDI3` → `PAIR0`–`PAIR3`). Only the last hop, pairs to jack
contacts, is out of order.

### Evidence

- **PCB netlist**, per-pad net assignments in `hw/pandore.kicad_pcb`, footprint
  `amphenol_RJE58-188-54x1-0x`, identical on both jacks:

  ```
  J8 (Internal Ethernet)  1:PAIR0+  2:PAIR0-  3:PAIR1+  4:PAIR1-  5:PAIR2+  6:PAIR2-  7:PAIR3+  8:PAIR3-
  J9 (External Ethernet)  1:PAIR0+  2:PAIR0-  3:PAIR1+  4:PAIR1-  5:PAIR2+  6:PAIR2-  7:PAIR3+  8:PAIR3-
  ```

- **PHY registers**, read on a running board: the PHY is gigabit capable
  (`ESTATUS` = `0x2000`, 1000BASE-T full duplex) and the uplink switch
  advertises gigabit (`GBSR` bit 11 set), but after the downshift the PHY no
  longer advertises it (`GBCR` = `0x0000`), while Linux still believes it does
  (`ethtool`: advertised `1000baseT/Full`). A mismatch between what the kernel
  advertises and what the PHY sends is the signature of an automatic downshift.
- **Bench test.** An adapter patch cord crimped in the board's order at one end
  (one twisted pair on each of 1-2, 3-4, 5-6, 7-8) and T568B at the other:

  ```
  r8169 0000:01:00.0 enp1s0: Link is Up - 1Gbps/Full - flow control rx/tx
  ```

  No downshift is logged. The same port and cable run at 100 Mbit/s with a
  standard cable. This also confirms that the footprint's pad numbers are the
  jack's contact numbers.

### Workaround — adapter patch cord

Board end crimped in the board's order, other end standard T568B. Only pins 4,
5 and 6 differ from a T568B cable. Plug viewed with the clip underneath and the
contacts facing you, pin 1 on the left:

| Pin | 1 | 2 | 3 | 4 | 5 | 6 | 7 | 8 |
|---|---|---|---|---|---|---|---|---|
| **Pandore end** | white/orange | orange | white/green | **green** | **blue** | **white/blue** | white/brown | brown |
| Other end (T568B) | white/orange | orange | white/green | blue | white/blue | green | white/brown | brown |

Between two Rev A0 boards, crimp **both** ends in the Pandore order. Label these
cords "Rev A0 only": between two ordinary devices they split pairs themselves and
still link at 100 Mbit/s, which hides the mistake.

### Fix for Rev B

On both jacks, `PAIR1` must land on contacts 3 and **6**, and `PAIR2` on **4**
and 5:

| Pad | 3 | 4 | 5 | 6 |
|---|---|---|---|---|
| Rev A0 | `PAIR1+` | `PAIR1-` | `PAIR2+` | `PAIR2-` |
| **Rev B** | `PAIR1+` | **`PAIR2+`** | **`PAIR2-`** | **`PAIR1-`** |

Polarity within a pair is corrected automatically by the PHY, but keeping it
straight costs nothing. As with ERR-001 and ERR-002 the net names read
plausibly; the check that catches this compares each jack contact against the
TIA-568 pairing, not against the net names.

---

## ERR-004 — Ethernet controllers have no MAC address

**Subsystem:** Ethernet — both `RTL8111H` controllers
**Severity:** Minor. Networking works, but the host has no stable identity on
the network.
**Affects:** Revision A0. Observed on two boards (`pandore16`, `flou`).
**Status:** Open. Software workaround in place (677_pandore ADR-013).

### Symptom

Each boot, both interfaces come up with a new, locally administered MAC
address, so a DHCP server hands the host a different IP address after a
reboot:

```
r8169 0000:01:00.0: can't read MAC address, setting random one
r8169 0000:02:00.0: can't read MAC address, setting random one
r8169 0000:01:00.0 eth0: RTL8168h/8111h, e2:d2:10:a8:f7:9d, XID 541, IRQ 135
```

### Root cause

The `pandore-eth` sheet has no configuration EEPROM, so each `RTL8111H` must
hold its MAC address in its internal eFuse, and on these boards it was never
programmed. The PCI subsystem ID also reads as Realtek's generic default, which
fits a controller that was never configured for this board.

### Evidence

- Kernel log, every boot, both controllers (above); the MAC changes from one
  boot to the next.
- `pandore-eth` sheet: `RTL8111H`, crystal, magnetics and passives only, no
  `93C46`/`93C56` EEPROM.

### Workaround

Software only. The OS gives the host a stable address derived from the machine
ID: 677_pandore's `pandore-setup` bridges the two ports (`br0`) with
NetworkManager's `cloned-mac-address=stable`. Without the bridge, the same
setting on each Ethernet connection does it. Existing boards could also have
their eFuse programmed with Realtek's programming utility, which needs a MAC
address allocated for each port.

### Fix for Rev B

Either program each controller's eFuse at production with an allocated MAC
address (two per board), or add a `93C46` EEPROM per controller and program
those.

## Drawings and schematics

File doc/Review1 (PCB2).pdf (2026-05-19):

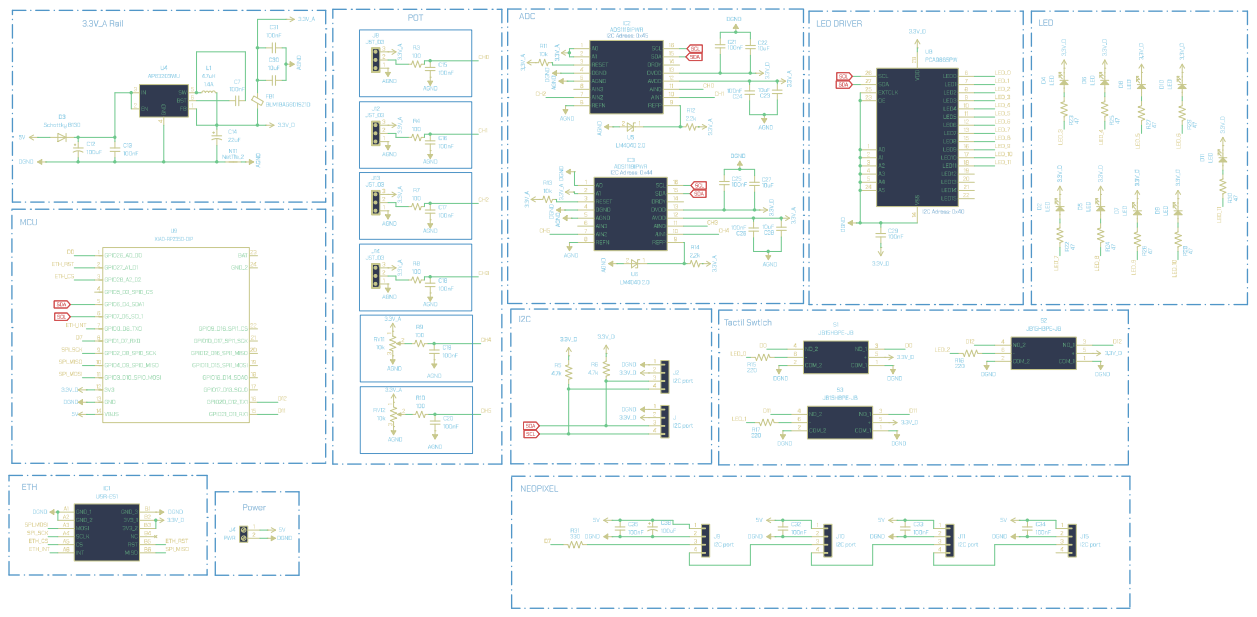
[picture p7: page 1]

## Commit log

2026-05-19 added production picture review added casing renders and interface pcb
    [rp2350.kicad_sch]
2026-05-19 added bringup document and generated ibom to help in manual assembly process
    [pandore-mdot2.kicad_sch]
2026-09-01 Add Pandore hardware technical reference (doc/pandore-skill.md)
    Publish the project's hardware knowledge base as a repo reference doc,
    generated from the Claude Code /pandore skill (personal paths, order
    numbers, and cost data removed).
    Highlights vs. prior docs:
    - Grove ports documented as 3.3V I2C (two independent mgmt-MCU buses,
    VSTBY-fed via PTC1/PTC2); recommend Qwiic / STEMMA QT sensors, not
    M5Stack (5V).
    - Fan headers corrected to 5V (not 12V) per pandore-fan.kicad_sch.
    - PTC1/PTC2 corrected: Grove-port protection, not USB VBUS.
    - ET20162 clarified as USB VBUS load switch (1A fixed).
    - Installed-part variants reconciled from purchase records
    (RJE58-188-5441, TE 440055-4, PTR902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
2026-09-01 Fix stale part data in README + reference doc
    Reconcile README against the current hardware reference:
    - Murata NXE2S1212MC is a 2W part (167 mA), not 1W (two places).
    - J8/J9 installed Ethernet jack is RJE58-188-5441 (BOM -5411 was
    backordered), not -5411.
    - J28/J29 are CPG-23 pogo pins tapping the Teensy's USB-D± pads, NOT
    USB-C receptacles; the only panel USB-C is the Teensy's own jack.
    Split the Teensy (U9) and pogo-pin (J28/J29) rows accordingly.
    - Status updated to PCBA-complete / hand-assembly-in-progress, with
    links to the interactive BOM and the A0 bring-up guide.
    doc/pandore-skill.md (regenerated): correct V3P3 budget to 3A (10W)
    and the same J28/J29 USB-C correction.
    Co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
2026-09-01 doc: correct OLED rail + cap values from Rev A0 netlist
    Verified J25 pad->net assignments directly from pandore.kicad_pcb and
    component values from pandore-mgmtmcu.kicad_sch. Four values in the
    OLED section were wrong:
    - Pin 5 (VDD, logic): VSTBY, not V3P3. VCC and VDD are separate nets.
    - Pin 22 (VCOMH): C230 = 10 uF, not 2.2 uF / 4.7 uF (the doc gave both,
    contradicting itself).
    - Pin 23 (VCC) decoupling: C231 = 10 uF || C228 = 100 nF, not 4.7 uF.
    Adds a "Verified from Rev A0 netlist" block recording the full pad->net
    map, the BS1/BS2 strap resolution (R194/R195 0R populated, R192/R193
    10k DNP -> 4-wire SPI), and a blank-but-powered bring-up checklist.
    This also documents why the "the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
2026-09-01 doc: finish sanitizing the public hardware reference
    The file's header claims personal paths, order numbers and cost data
    were removed, but several items survived the first pass. Removed:
    - The private firmware repo's host and project path. The repo is now
    referred to generically as <firmware-repo>; its internal layout is
    still documented because that part is useful, but it no longer
    advertises a private server address from a public repository.
    - PCBA payment figures (per-unit and total).
    - References to invoices and purchase records as sources. The part
    choices they backed are kept — only the provenance wording changed,
    so no technical content is lost.
    Left in place deliberate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
2026-09-01 doc: add Rev A0 errata, ERR-001 (CS4272 I2C SDA/SCL crossed)
    SDA and SCL are transposed on the isolated side of the ISO1640 (U24):
    SDA2 lands on the CS4272's SCL pin (U11.11) and SCL2 on its SDA pin
    (U11.12). The codec therefore never ACKs, and cannot be configured over
    I2C at all -- no I2S audio in either direction, despite the I2S clock and
    data lines being correct.
    Confirmed from the Rev A0 netlist (hw/pandore.kicad_pcb per-pad net
    assignments). The CS4272 pinout was checked against an independent
    CS4272 design, doc/reference/SuperAudioBoard_Schematic.pdf, rather than
    relying on this project's own symbol library: pin 11 = SCL, pin 12 = SDA
    in both. The reekilib CS4272 and ISO1640 symbols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
2026-09-01 doc: record R273 monitor-pot wiring, isolation, and switch behaviour
    Verified from the Rev A0 netlist. Three things that were not documented:
    Topology. R273's two wipers feed 5.1k resistors (R264/R269) into an
    OPA1656 summing junction -- a Baxandall-style active volume control, not
    a divider to ground. Full pad->net table added.
    The pot cannot be read in software, and must not be wired to an ADC.
    Neither wiper reaches an ADC anywhere. The monitor chain runs on AV5
    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
2026-09-18 doc: confirm ERR-001 with designer, document host-path consequence
    Laurence Deschenes Villeneuve confirmed on 2026-09-02 that the CS4272's
    SDA and SCL pins were transposed in the Rev A0 design. ERR-001 is no
    longer a netlist-derived hypothesis; the root cause is established. The
    EXP8 bench probe stays, demoted to a one-time check that the boards match
    the design.
    Add a section on the LattePanda Mu path. AUDMST is a shared segment: the
    Teensy and the Mu's I2C2 both cross U24 to reach the codec, so both hit
    the transposition, but they are not equally recoverable. The Teensy
    bit-bangs and can simply swap the pin roles. A hardware I2C master cannot
    run with SCL and SDA exchanged, so the host ne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
2026-09-18 doc/errata: de-link the BIOS customization request
    The request document has moved to the private software repo, so the
    relative link from the errata would 404 on GitHub. The cross-reference
    is kept as prose; only the link is removed.
2026-09-18 doc: fix JMP12 / JMP15 in the hardware reference
    JMP12 AUTOON and JMP15 PON are easy to confuse and the reference had
    them conflated:
    - JMP12 "AUTOON" is the 2-pin hardware auto-power-on (pad 1 -> Q12
    drain, pad 2 -> PWRSW). Shorted, Q12 pulses PWR_BTN# on power-up --
    the mechanism LattePanda's design guide recommends over the BIOS
    "Restore AC Power Loss" setting.
    - JMP15 "PON" is a 3-pin power-state select (MGMTMON.S3 / MGMTMON.PWR /
    MGMTMON.S0), tying the Mgmt-MCU power monitor line to S3 or S0. It is
    not the auto-power-on jumper.
    Split out of the original local commit, which also added the BIOS
    customization request; that document has moved to the private software
    repo and is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
2026-09-18 doc: correct MIDI section from Rev A0 netlist
    The MIDI section described the DIN ports as hardwired through the Teensy
    to USB MIDI. They are not: both lines pass through 3-pin selector
    jumpers and serve either the Teensy or the LattePanda Mu, not both.
    Verified from hw/pandore.kicad_pcb:
    - JMP1 "MIDIRX" / JMP2 "MIDITX", pin 2 is the common. Shunt 1-2 for the
    Teensy, 2-3 for the Mu. One jumper each way gives the half-working
    case (IN to one processor, OUT from the other).
    - Teensy side is Serial8: IO34 = RX (U9.26, UART8.RX), IO35 = TX
    (U9.27, UART8.TX). Host side is UART2 (U1.140 RXD / U1.138 TXD).
    - MIDI IN (J10): pin 4 -> R51 220R -> H11L1 (U10) LED, pin 5 -> D17.
    U10 has a push-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
2026-09-18 doc: correct fan ownership; add host OS, Teensy power gate, Grove ecosystem
    Fan control was attributed to the Management MCU in five places. It is
    wrong. FANCPU{TAC PWM} and SYSCPU{TAC PWM} terminate in
    pandore-cpumod.kicad_sch on the Mu's native FAN_CTL/FAN_TAC pins, and
    the strings FANCPU/SYSCPU appear zero times in pandore-mgmtmcu.kicad_sch.
    Confirmed independently by Laurence. Fans are handled by the Mu's
    BIOS/OS thermal management; no MCU firmware can drive them. Also records
    that the fan rail is +5V (the fan sheet's VDD net resolves to V5), not
    +12V, with the Intel 4-wire cable pinout and the 5V-tolerant TACH note.
    Host OS: the Mu runs Linux, specifically CachyOS. The Windows Pico-SDK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
2026-09-19 errata: ERR-002 — Teensy/codec I2S signals rotated across the isolator
    No audio passes in either direction on rev A0, while the CS4272 itself measures
    healthy: configured over I2C, running as I2S/clock master off crystal X5 at
    exactly 48 kHz, references correct, output amplifiers enabled.
    The I2S signals between the Teensy and the codec cross the ISO7762 (U23)
    through 0R quad arrays R168/R169 (YC124, which pairs 1-8/2-7/3-6/4-5), and the
    assignment comes out rotated. Only LRCK and ~RST land correctly. Two results
    are independently fatal: the Teensy's TX data pin is tied to the codec's SDOUT
    (output against output, no path to SDIN), and the codec's SDIN is driven from
    the Teensy's MCLK pin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
2026-09-19 errata: ERR-002 — record why no SAI remap can recover this
    The "no software workaround" claim was asserted rather than shown. Replace it
    with the pad tables it rests on, so the next person does not have to re-derive
    them.
    Remapping is not impossible in general: the IMXRT has daisy-chain SELECT_INPUT
    registers for SAI1_RX_BCLK, RX_SYNC and RX_DATA0-3, and SAI1's data lines can be
    assigned to several pads. The reachable pads simply are not the ones this board
    uses -- TX_DATA can go to 6/7/9/32 but the codec's SDIN is fed from IO23;
    RX_DATA can come from 6/8/9/32 but the codec's SDOUT lands on IO7; RX_BCLK is
    pin 21 only while the codec's SCLK lands on IO8. LRCK is the one that matches.
    The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
2026-09-21 errata: ERR-002 — show that the Teensy pin numbers in the bodge are verified
    The rework instructions name Teensy IO numbers, but the U9 symbol labels its
    audio pins by function (AUDIO.O1A, AUDIO.MCL1, ...) rather than by IO number, so
    the mapping looked like something the reader would have to take on trust.
    Record how it was established instead of assumed: the symbol numbers pins in
    physical pad order and names most of them IOxx, so each function-named audio pin
    is fixed by its explicitly numbered neighbours. IO22 at pin 44 falls inside the
    second run, anchoring that sequence from both directions. The same argument
    gives UART8.RX/TX as IO34/IO35, the DIN MIDI pair.
    Consistent with the i2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
2026-11-08 devcase: fond devkit V2, une pièce, ports en U ouverts vers le haut
    Suggestions d'Alex Burton pour transporter et manipuler la carte sans
    stress :
    - plaque monobloc avec rebord sur tout le contour, à la hauteur des
    prises Ethernet (15 mm au-dessus de la carte) ; on dépose la carte ;
    - tous les ports ouverts en U vers le haut ;
    - inserts thermiques M2.5 dans les 8 plots (vis M2.5 x 6 tête bombée) ;
    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
2026-11-08 devcase: nervures en losange, saillie max à la hauteur de la carte
    Les nervures des languettes minces sont maintenant en losange : 6 mm de
    saillie à la hauteur de la carte (la racine des languettes, là où elles
    casseraient), puis elles se résorbent pour affleurer la paroi au bas du
    fond. Rien ne dépasse au plateau ; le dessous fait 22° avec la verticale,
    donc toujours sans support (la console avertit au-delà de 45°).
    Curseur nervure_bas renommé nervure_max ; nouveau curseur nervure_z_max.
    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
